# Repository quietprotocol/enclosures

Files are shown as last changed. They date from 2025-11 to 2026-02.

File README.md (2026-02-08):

# OpenMANET Enclosures

This repository collects 3D-printable and off-the-shelf enclosure designs that support OpenMANET nodes and accessories.

## Available Enclosures

| Name | Description |
|---|---|
| [Get Started Enclosure](GetStarted/README.md) | Simple Snap-fit Raspberry Pi 4 + HaLow enclosure with multiple UPS/no-UPS variants and ABS/ASA print guidance. |
| [OpenNot5](OpenNot5/README.md) | Aluminum or 3D printed field chassis that integrates a Pi 4B, Waveshare 3S UPS, and waterproof bulkhead connectors. MakerWorld listing: https://makerworld.com/en/models/2128181-openmanet-radio-case |
| [OpenChubNET](OpenChubNET/README.md) | 3D printed, Pi4B, Waveshare UPS D, CAZN connectors. Option for DIY top lids |
| [Hammond Enclosure](Hammond/README.md) | OpenMANET enclosure for a Pi 4B using a Hammond 1457K1201BK case plus printed cap/carrier tray; optional inline connector simplifies switch-to-PiSugar wiring for easier rework. |

## Other Prints

| Name | Description |
|---|---|
| [GIZOisNT](GIZOisNT_Antenna/README.md) | Tactical Gooseneck Antenna |

## Photo Gallery

**Get Started**

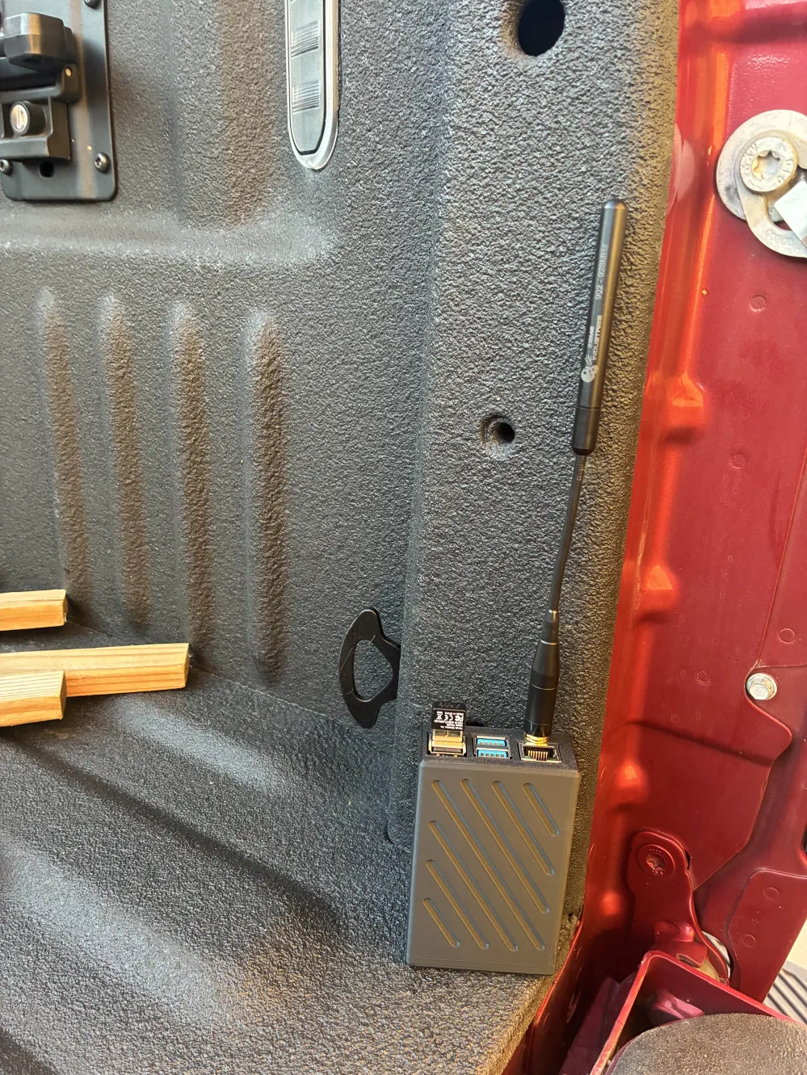
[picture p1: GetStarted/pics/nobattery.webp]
Get Started no-UPS build


**OpenNot5**

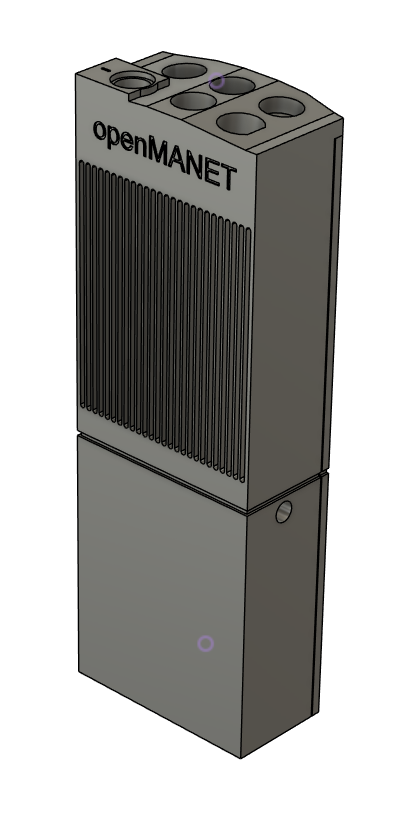
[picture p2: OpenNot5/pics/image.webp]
OpenNot5 field build


**OpenChubNET**

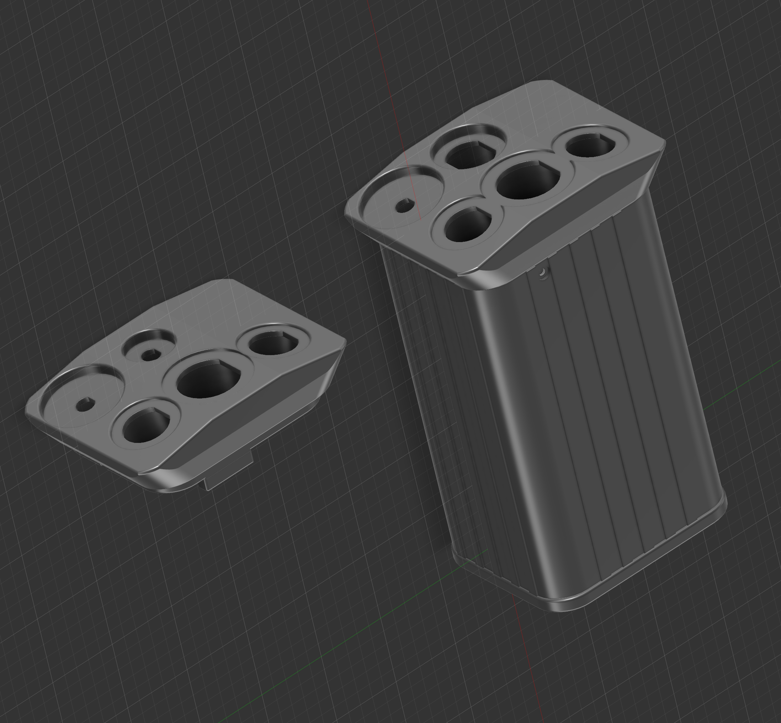
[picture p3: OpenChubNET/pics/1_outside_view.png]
OpenChubNET render


**Hammond**

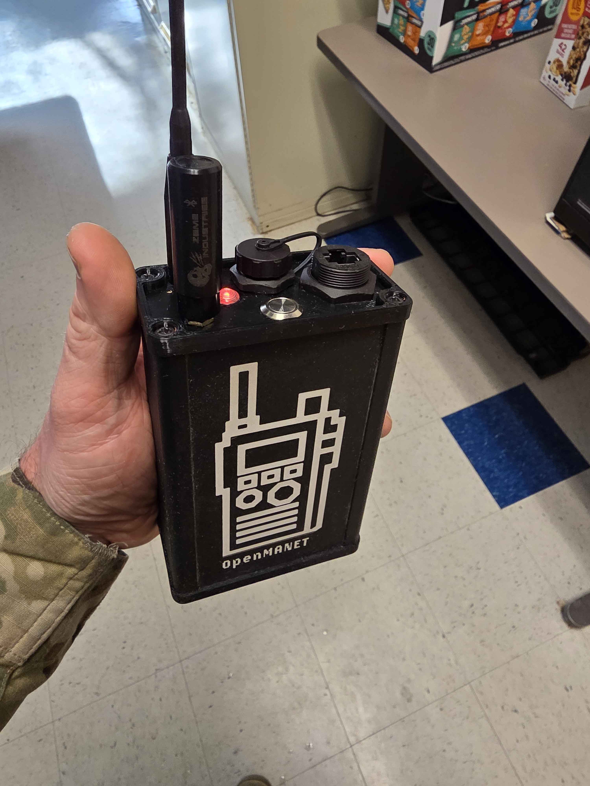
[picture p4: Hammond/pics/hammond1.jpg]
Hammond enclosure front angle


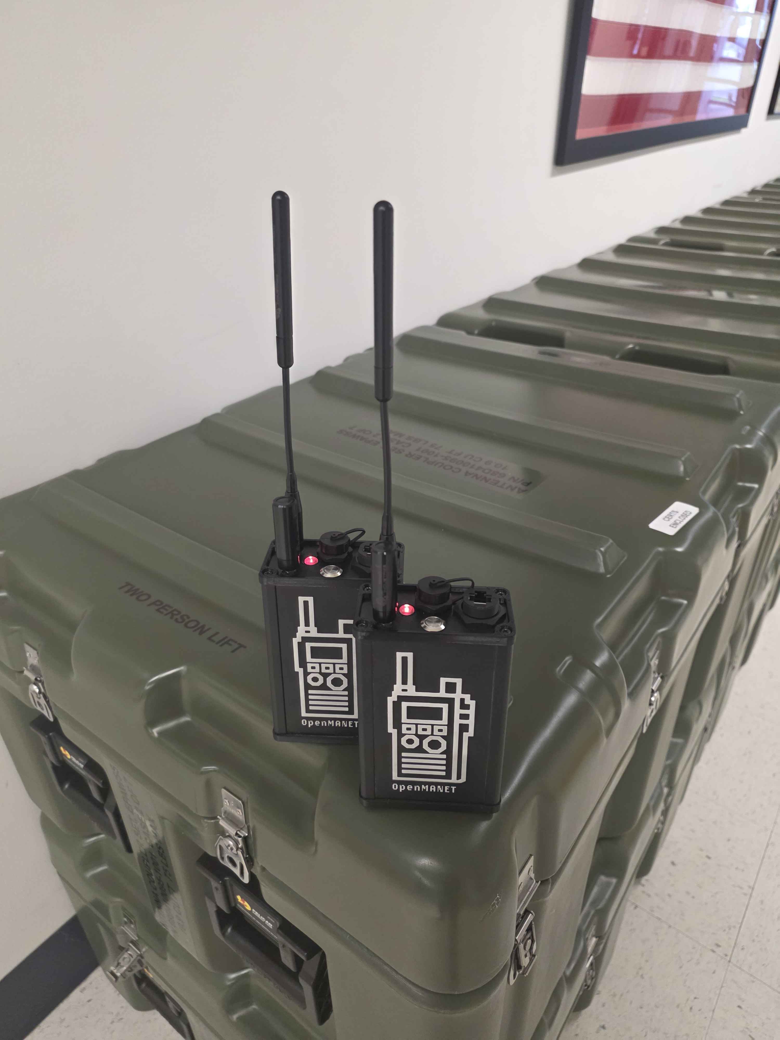
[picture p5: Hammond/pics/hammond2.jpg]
Hammond enclosure rear angle


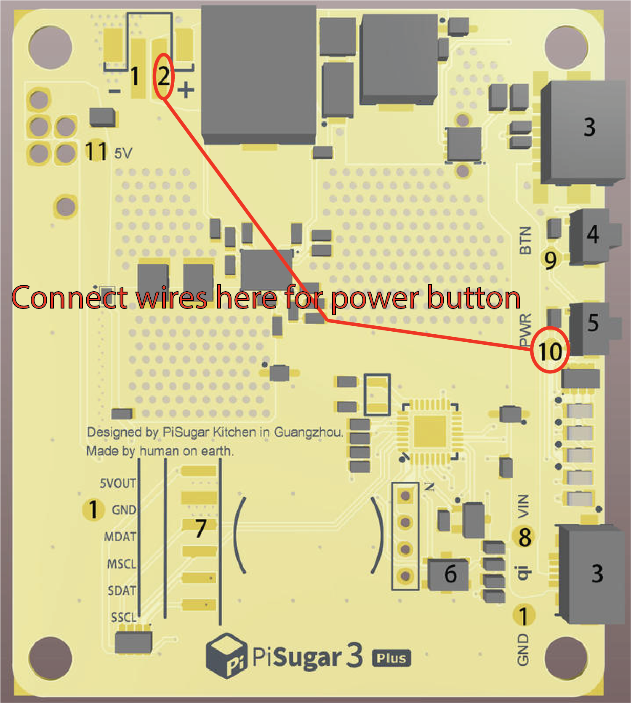
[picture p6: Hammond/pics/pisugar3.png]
Hammond enclosure open with PiSugar 3 Plus


**GIZOisNT**

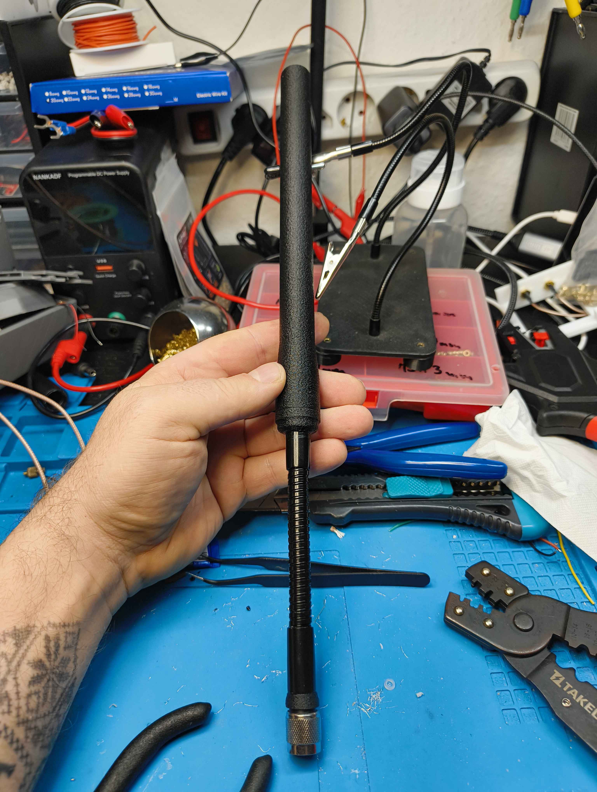
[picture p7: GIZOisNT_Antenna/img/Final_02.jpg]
GIZOisNT


## Contributing

1. Create a directory named after your enclosure.
2. Add a `README.md` describing the use case, assembly steps, and parts list (note optional vs required parts).
3. Include any supporting assets (STL files, wiring diagrams, photos) inside the same directory.

PRs that follow the structure above make it easier for others to build repeatable OpenMANET hardware.

## License

All content in this repository is provided under the [Creative Commons Attribution-NonCommercial 4.0 International](LICENSE) license. Commercial use requires explicit permission from the creator.

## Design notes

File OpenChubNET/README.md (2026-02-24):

# OpenChubNET Enclosure

## Overview
This enclosure is designed for OpenMANET field nodes and integrates a Pi 4B with an internal battery-backed UPS.

## Philosophy

- A large enough case to fit the bulkiest SBC + UPS + Hat configuration. Room on one side of the case to pass through thin USB to power and USB eth.
- A mounting board that the SBC sits on which slides into the case, it has holes to pass through cables. The board translates different SBC + UPS + Hat configurations to fit the case
- Multiple top lids with various antenna configurations depending on antenna types, number of antennas, Power over USB, EUD eth over USB, buttons etc.

## Order of build

1. Print files 
2. Mount the Pi4B and Waveshare UPS D to the printed mounting plate. Use the Waveshare UPS D flat head screws
3. Add the Li-ion battery and wiring
5. Assemble connectors to lid
6. Connect antennas
7. Connect USB cables to hardware
8. Install and test OpenMANET as per [instructions](https://openmanet.github.io/docs/initial-setup.html)

Assembly images can be found at https://www.instagram.com/p/DSH5yTLCO6E

## Parts List

### Baseline
- 1 x Raspberry Pi 4B
- 1 x [Waveshare UPS HAT D](https://www.waveshare.com/ups-hat-d.htm)
- 2 x 21700 3.7V rechargeable lion batteries

### Connectors
- 2 x [CAZN USB-C waterproof port](https://www.aliexpress.us/item/3256806032665821.html)
- 1 x [CAZN RJ45 waterproof](https://www.aliexpress.com/item/1005006207254042.html)
- (alternative) 1 x [CAZN RJ45 waterproof 180 degrees](https://www.aliexpress.com/item/1005006207174223.html)

### Antenna cables
- 1 x [NType to UFL RG178 20cm](https://www.aliexpress.com/item/1005008877279360.html)
- 1 x [SMA to UFL 20cm](https://www.aliexpress.com/item/1005005697399884.html)

### Antennas
- 1 x [Gizont 915MHz gooseneck NType](https://www.aliexpress.com/item/1005006433957349.html)
- 1 x [Gizont GPS Stubby](https://www.aliexpress.com/item/1005006022171372.html)

## Options

### Antenna cables

I went with NType and thicker RG178 cables, but TNC or SMA options are available at resellers.

### Antennas

Gooseneck, whips, spring flexible. Check out Gizont store on Aliexpress

### Aliexpress resellers

- [Gizont Factory Store](https://www.aliexpress.com/store/1103206200)
- [CAZN Factory Store](https://www.aliexpress.com/store/1103206200)

## Print instructions

### Case

Print standing up. No supports needed

- [Case](stl/openMANET_enclosure_rpi4_ups_battery_rj45.stl)

### Mounting plate

Print laying down. No supports needed

- [Board](stl/openMANET_mounting_plate.stl)

### Top

Print laying down or at 45 degree for fewer supports. Supports needed.

- [usbc rj45 ntype sma](stl/openMANET_top_usbc_rj45_ntype_sma.stl)
- [usbc rj45 sma sma](stl/openMANET_top_usbc_rj45_sma_sma.stl)

## DIY top lids

There is a [top lid stencil](stl/openMANET_stencil_top.stl) which can be use to punch out holes to your liking

Additionally there are punches for 

- [CAZN RJ45](stl/openMANET_stencil_cazn_rj45.stl)
- [CAZN USB](stl/openMANET_stencil_cazn_usb.stl)
- [NType](stl/openMANET_stencil_ntype.stl)
- [SMA Large](stl/openMANET_stencil_sma_large.stl)
- [SMA Small](stl/openMANET_stencil_sma_small.stl)

In Fusion 360 add the stencils to the top, combine, cut. 

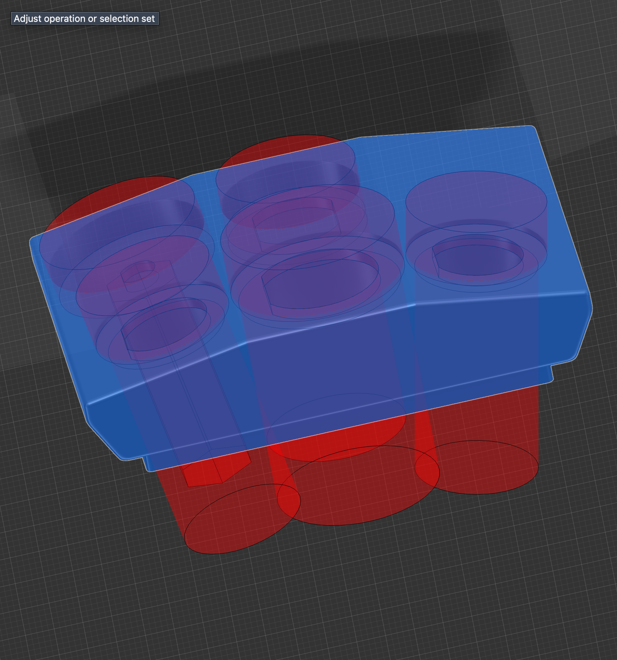
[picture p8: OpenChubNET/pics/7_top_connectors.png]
Result


## Bambu Labs project

- [OpenChubnet slim](stl/OpenChubnet_slim.3mf)

## Reference images

Outside view
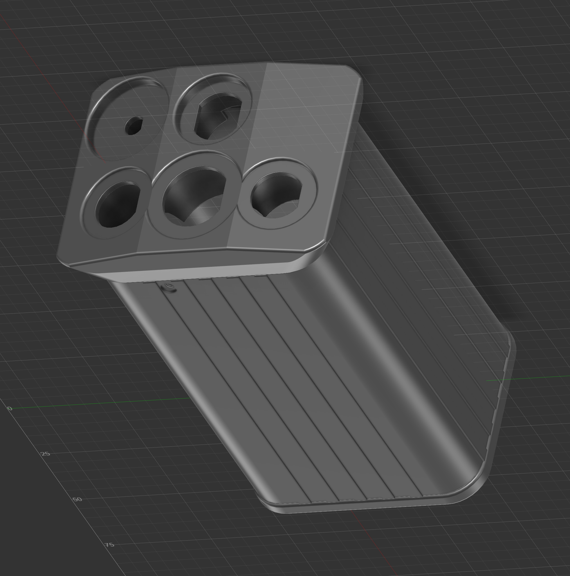
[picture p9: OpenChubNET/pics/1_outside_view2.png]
Outside view

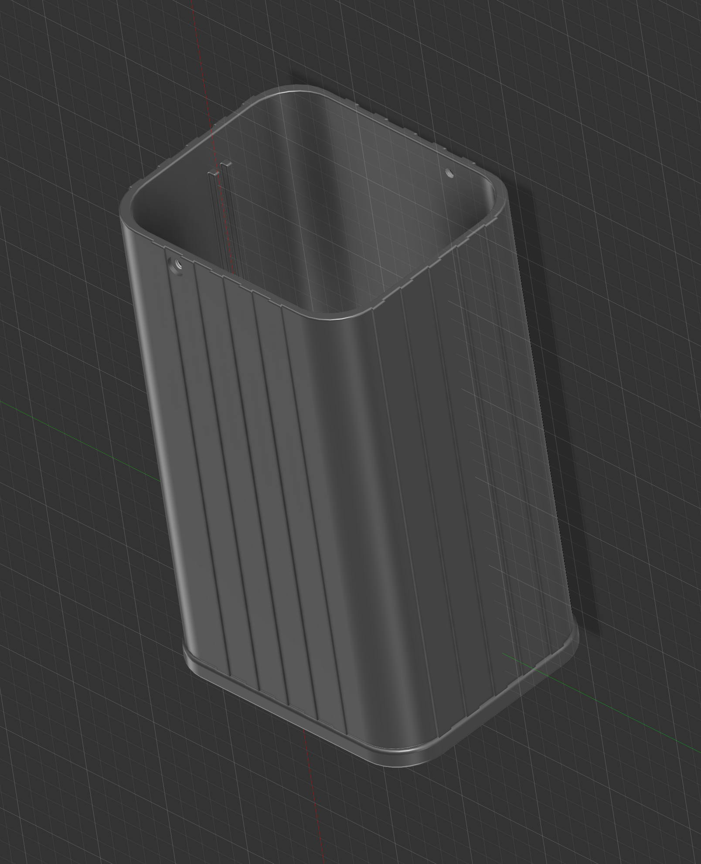
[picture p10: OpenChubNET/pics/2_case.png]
Case

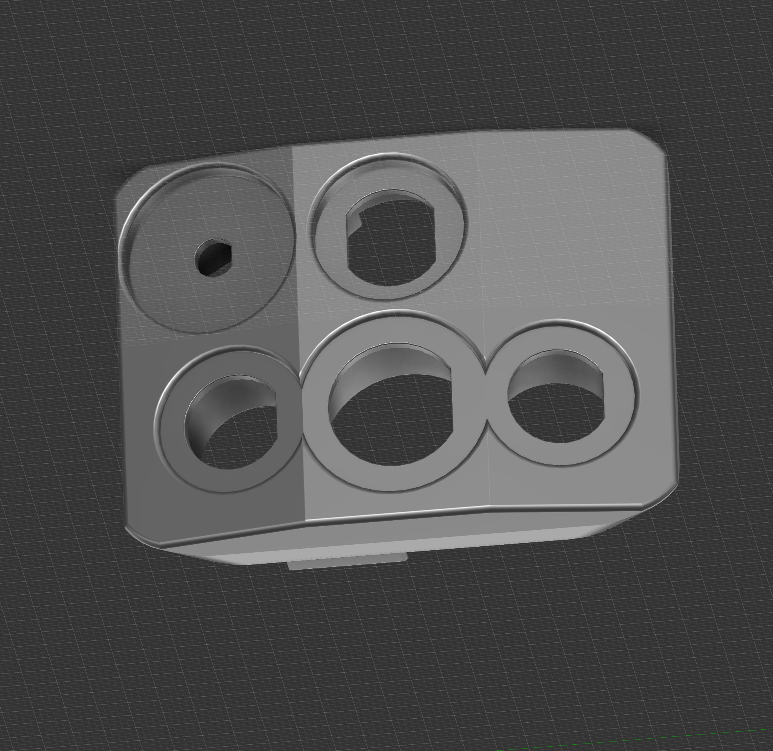
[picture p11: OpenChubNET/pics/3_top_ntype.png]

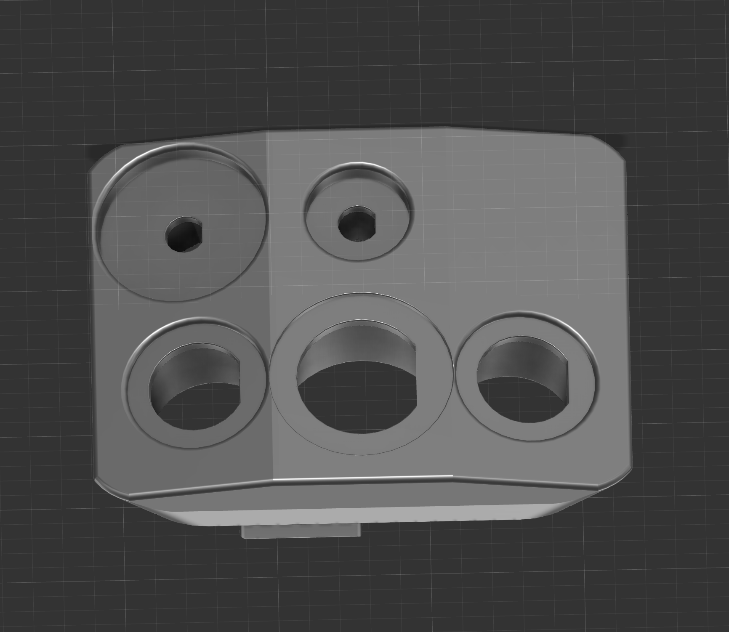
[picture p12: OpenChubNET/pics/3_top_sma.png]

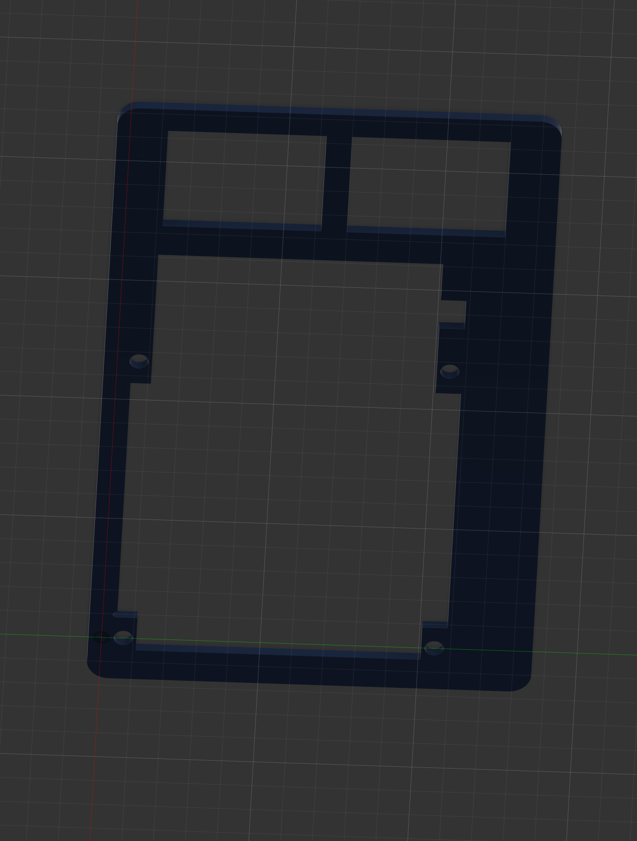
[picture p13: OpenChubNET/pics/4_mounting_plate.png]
Mounting plate

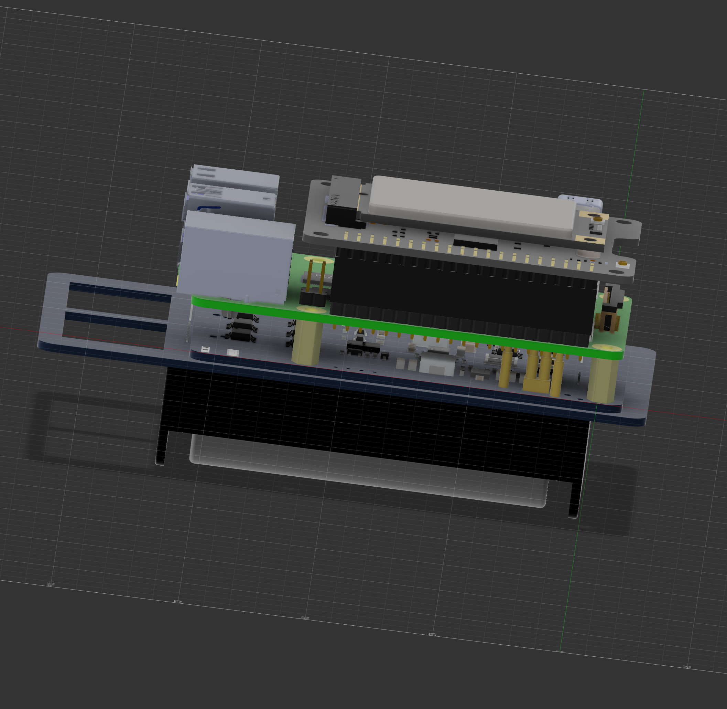
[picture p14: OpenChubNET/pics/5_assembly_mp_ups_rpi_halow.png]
Assembly 1

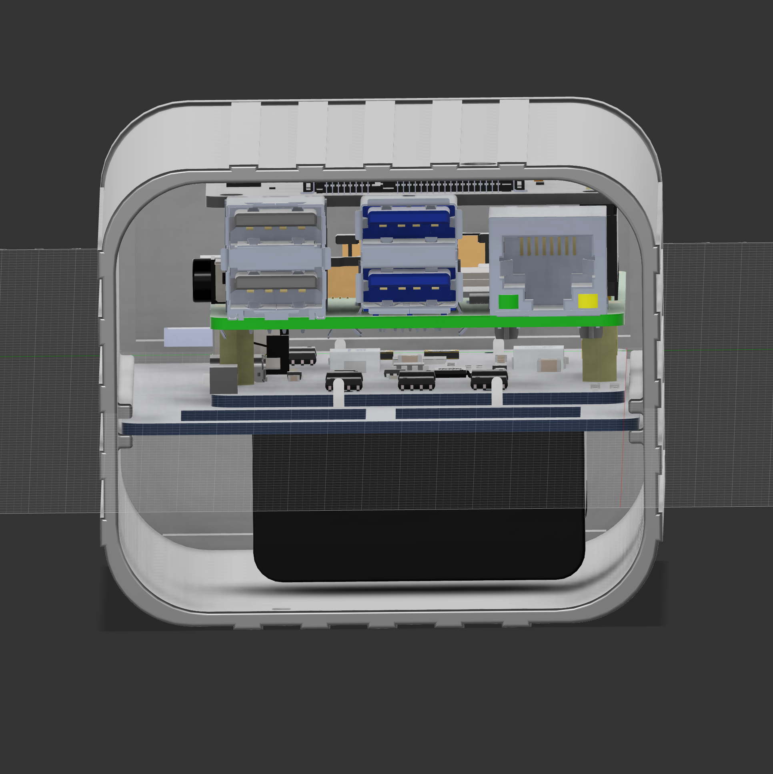
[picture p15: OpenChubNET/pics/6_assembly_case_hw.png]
Assembly 2


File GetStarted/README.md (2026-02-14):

# Get Started Enclosure

This directory captures the baseline enclosure that ships with Get Started kits. It houses a Raspberry Pi 4, HaLow radio, and optional UPS hardware inside a snap-fit shell that prints on a 220 mm bed.

## Overview

- Three variants share the same IO layout but differ in battery accommodation: Pisugar UPS, Waveshare UPS D, or a no-UPS shell.
- Lid uses a flexible latch that survives repeated openings when printed in ABS/ASA.
- External buttons are split into a separate part to keep tolerances tight and maintain layer adhesion.

## Reference Photo

No-UPS reference build

> Add additional perspective photos to `pics/` so other builders can see connector routing and antenna placement.

## Variant Files

| Variant | Main Body / Hatch STL | UPS Support | SMA to U.FL Pigtails |
|---|---|---|---|
| Pisugar UPS | `open manet enclosure pisugar ups main body.stl`, `open manet enclosure pisugar ups hatch.stl`, `open manet enclosure pisugar ups external buttons.stl` | Pisugar 3 power platform | 2 × 6" pigtails |
| Waveshare UPS D | `open manet enclosure WAVESHARE UPS D main body.stl`, `open manet enclosure WAVESHARE UPS D hatch.stl` | Waveshare UPS D + 18650 sled | 1 × 6" pigtail |
| No UPS | `open manet enclosure no ups main body.stl`, `open manet enclosure no ups hatch.stl` | None – direct external power | 1 × 6" pigtail |

All CAD source files (`*.f3z`) for each variant are included for remixing. Keep the SMA jack spacing consistent so the hatch remains reusable between versions.

## Printing Guidance

- Strongly prefer ABS or ASA for every structural part; the enclosure runs warm and the snap joints need ductility.
- Orient the main body with the front face down so the internal standoffs print cleanly and support the Pi with minimal cleanup.
- Print the external button part flat on its back so perimeters align with the travel direction—this maximizes layer adhesion across the narrow bridge between buttons.
- Use 0.2 mm layers, 4 perimeters, and ≥30% infill for the main body; lids can drop to 3 perimeters.

## Recommended Parts

| Item | Optional | Notes |
|---|---|---|
| Wio WM6180 Wi-Fi HaLow mini PCIe Module | No | Primary radio |
| WM1302 Pi Hat | No | Mate the HaLow card to the Pi |
| External Antenna 868/915 MHz 2 dBi SMA Foldable | No | Two ports for UPS builds, single port for no-UPS |
| [ZBM2 Mesh Goose Neck](https://zbm2industries.com/products/mesh-goose-neck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) | Yes | 915 MHz LoRa/HaLow option with higher gain |
| [ZBM2 Mesh Stubby](https://zbm2industries.com/products/mesh-stubby) | Yes | Compact Bluetooth/short-range diagnostic antenna |
| SMA to U.FL cable assembly, 6" (150 mm) | No | Qty depends on variant above |
| Raspberry Pi 4 Model B (1 GB or greater) | No | Core compute |
| 21700 Rechargeable Batteries | Yes | Only for UPS builds that support them |
| Waveshare UPS B/D board | Yes | Use with corresponding enclosure files |
| Pisugar UPS 3 | Yes | Use with Pisugar variant |
| Panda PAU06 USB Wi-Fi Adapter | Yes | Optional client radio |
| USB GPS Receiver (u-blox based) | Yes | Optional timing source |

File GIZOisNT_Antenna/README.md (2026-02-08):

"Mom, can we have GIZONT tactical gooseneck antennas?" - "We have GIZONT actical gooseneck antennas at home...!"

[the GIZONT... GIZOisNT we have / make at home] 

GIZOisNT 

# The GIZOisNT Tactical Gooseneck Antenna
### What the heck is this?
The "GIZOisNT" antenna isn't an antenna in the traditional sense. It's more of a protective housing for various types of antennas. The GIZOisNT is a platform for mounting different antennas (WiFi, LoRa, HaLow, etc.) in the style of tactical antennas, such as those found on the Persistent Systems MPU5 or Silvus StreamCaster. GIZONT, on AliExpress, is probably the best-known manufacturer of mockup antennas.

### Why should I build my own antennas?
The original antennas for tactical digital radios can cost up to 300 EUR/USD, if they're even available. Even then, there's no guarantee they'll be suitable for your project. Of course, you could look for suitable mockups on AliExpress, which are available for 25-35 EUR/USD, but with considerable waiting times.

Or: you could order the individual parts from Amazon (1-2 day delivery), take some time for 3D printing those files, and build the perfect antenna for your project at home for under 15 EUR/USD each (incl. the actual antenna).

### What do I need?
The list of required parts and tools is quite manageable. You'll need a soldering iron (fine tip) and solder. Wire strippers, side cutters, and crimping pliers. And of course, you'll need a 3D printer. The individual components required are: a [gooseneck](https://www.amazon.de/dp/B0C2NDY4RJ) (12cm long, 10mm diameter internal and external threads), a [male TNC connector](https://www.amazon.de/dp/B0D9LDKLXH?th=1), a [male RP-SMA connector](https://www.amazon.de/dp/B08F4SX8YJ?th=1), and [RG316 coaxial cable](https://www.amazon.de/dp/B09PT81P3N?th=1). Last but not least, you'll need the appropriate antenna. Since I built this antenna for a different project, I'm using a [2.4/5GHz antenna](https://www.amazon.de/dp/B06XB92KNF). Regardless of which antenna you ultimately install in the GIZOisNT, the connector must be RP-SMA, and the antenna diameter must not exceed 13mm. Three tubes are available in different lengths: 100mm, 150mm, and 200mm.

### Where do I start?
It's very simple: first, you download the necessary print files. You can find a list of the individual parts [here](<model files/content.md>). You can either experiment with your own printer settings or use [my presets](<printer files/printer_settings.md>). If you're using an Anycubic Kobra S1, you can directly process the included 3MF file. However, if you're using the Orca, Prusa, or Bambu slicer, you can load the 3MF file, but you may need to make some adjustments.

I suggest you print the individual parts in two batches: first the small parts, and then the tube. The tube takes a very long time to print, so you can start working on the small parts in the meantime. Even if you plan to build multiple GIZOisNTs, print the small parts first, then the tubes.

### What's next?
Once your parts are printed, follow my [assembly guide](img/assembly/assembly.md).

---

The GIZOisNT antenna was developed by [audiocustoms](https://github.com/audiocustoms) for [ORBIS Mesh](https://github.com/ORBIS-Mesh) and [openMANET](https://openmanet.github.io/docs/).

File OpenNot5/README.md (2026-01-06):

# Open Not 5 Node Enclosure

## Overview
This enclosure is designed for OpenMANET field nodes and integrates a Pi 4B with an internal battery-backed UPS.  
The aluminum chassis doubles as a passive heatsink and keeps all IO accessible through waterproof bulkhead ports. This also can be 3D printed but may get hot.

Example enclosure build

Printable files and build notes are on MakerWorld: https://makerworld.com/en/models/2128181-openmanet-radio-case

## Assembly
1. Print files 
2. Mount the PI4B and UPS
3. Add the Li-ion battery and wiring
4. add antennas
5. Seal using waterproof screws and gasket.

## Parts List
 - Raspberry Pi 4B (4 GB preferred)
 - [Waveshare 3S UPS Module](https://www.amazon.com/waveshare-Uninterruptible-UPS-Module-3S/dp/B0BQC2WNR8/) with 12 V barrel output and on/off button
 - 4 × SMA-to-PEX bulkhead connectors with O-rings
 - [CAZN USB-C waterproof port](https://www.aliexpress.us/item/3256806032665821.html)
 - 1 × [ZBM2 Mesh Stubby antenna](https://zbm2industries.com/products/mesh-stubby) for Bluetooth diagnostics
 - 1 × 915 MHz LoRa antenna (SMA) – [ZBM2 Mesh Goose Neck](https://zbm2industries.com/products/mesh-goose-neck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)
 - 2 × dual-band (2.4/5 GHz) Wi-Fi antennas (SMA)
 - 1 × GPS puck antenna (SMA or MMCX depending on receiver)

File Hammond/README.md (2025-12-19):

# Hammond Enclosure

OpenMANET enclosure for a Raspberry Pi 4B that uses a Hammond 1457K1201BK case with a printed cap and carrier tray. An inline connector between the power switch and the PiSugar can be added to make disassembly and reassembly easier.

## Photos

Hammond enclosure front angle

Hammond enclosure rear angle

Hammond enclosure open with PiSugar 3 Plus

## Bill of Materials

| # | Part | Qty | Part Number | Link | Vendor/Notes |
|---|---|-----|---|---|---|
| 1 | Enclosure | 1 | 1457K1201BK | https://www.hawkusa.com/manufacturers/hammond-mfg/enclosures/1457k1201bk | Hammond |
| 2 | Pi 4B | 1 | Any model | https://www.digikey.com/en/product-highlight/r/raspberry-pi/raspberry-pi-4-model-b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 | — |
| 3 | Light pipe | 1 | LCS_072_CTP | https://www.digikey.com/en/products/detail/visual-communications-company-vcc/LCS-072-CTP/5156883 | VCC |
| 4 | Wi-Fi HaLow card | 1 | Wio-WM6108 | https://www.seeedstudio.com/Wio-WM6180-Wi-Fi-HaLow-mini-PCIe-Module-p-6394.html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 | Seeed |
| 5 | Wi-Fi hat | 1 | WM1302 | https://www.seeedstudio.com/WM1302-Pi-Hat-p-4897.html | Seeed |
| 6 | USB-C connector | 1 | E10 FPC-BF-F/PFC-A-M- | https://www.aliexpress.us/item/3256806033375623.html | Cazn, 0.2 m |
| 7 | RJ45 connector | 1 | RJ45-TF1-F/RJ45-M- | https://www.aliexpress.us/item/3256806020939290.html | Cazn, 0.3 m |
| 8 | u.fl to RP-SMA pigtail | 2 | Any | https://www.aliexpress.us/item/3256809083730864.html | 8 cm |
| 9 | Button | 1 | GQ12H2 | https://www.amazon.com/dp/B08R9P9DFC/ | Gebildet |
| 10 | PiSugar 3 Plus | 1 | — | https://www.pisugar.com/products/pisugar-3-plus-raspberry-pi-ups | PiSugar |

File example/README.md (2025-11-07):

# Example Enclosure

This sample enclosure documents the expected level of detail for OpenMANET builds. Use it as a starting point when you document your own hardware, swapping in your enclosure-specific files, wiring notes, and mechanical considerations.

## Overview

- Houses a Raspberry Pi 4, HaLow radio, antennas, and optional power accessories.
- Demonstrates how to call out required vs optional parts so builders can adapt to their needs.
- Intended for field-friendly deployments where ruggedness and quick maintenance matter.

## Reference photo

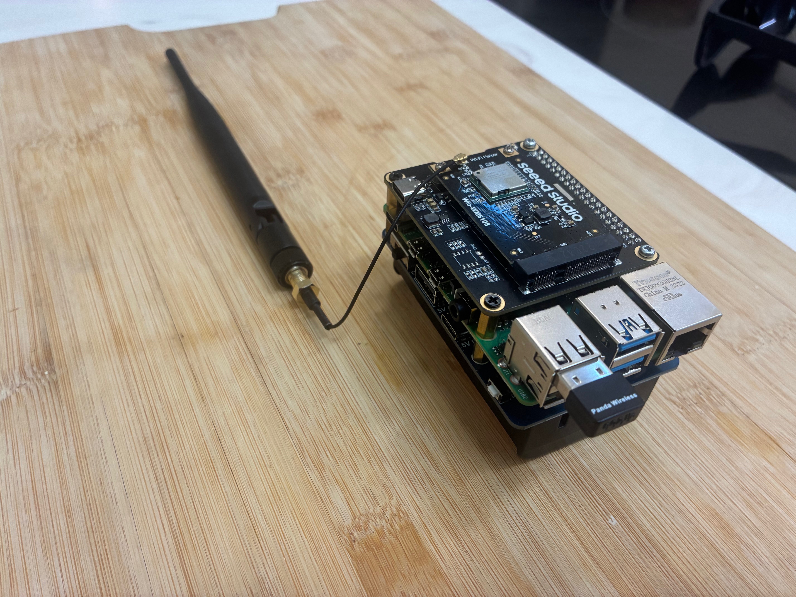
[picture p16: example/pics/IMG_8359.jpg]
Example enclosure build


> Store high-resolution photos inside a `pics/` subdirectory (or similar) and link to them with relative paths so GitHub renders the image inline.

## Recommended Parts List

| Item | Optional |
|---|---|
| [Wio WM6180 Wi-Fi HaLow mini PCIe Module](https://www.seeedstudio.com/Wio-WM6180-Wi-Fi-HaLow-mini-PCIe-Module-p-6394.html) | No |
| [WM1302 Pi Hat](https://www.seeedstudio.com/WM1302-Pi-Hat-p-4897.html) | No |
| [External Antenna 868/915 MHz 2 dBi SMA Foldable](https://www.seeedstudio.com/External-Antenna-868-915MHZ-2dBi-SMA-L195mm-Foldable-p-5863.html) | No |
| [UF.L to SMA-K 1.13 mm Cable (120 mm)](https://www.seeedstudio.com/UF-L-SMA-K-1-13-120mm-p-5046.html) | No |
| [Raspberry Pi 4 Model B (1 GB or greater)](https://www.seeedstudio.com/Raspberry-Pi-4-Computer-Model-B-1GB-p-4078.html) | No |
| [21700 Rechargeable Batteries](https://www.amazon.com/dp/B0D3GX96H6?ref_=ppx_hzsearch_conn_dt_b_fed_asin_title_4) | Yes |
| [WaveShare UPS B (18650 version)](https://www.amazon.com/gp/product/B0D39VDMDP/ref=ox_sc_saved_title_1?smid=A3B0XDFTVR980O&psc=1) | Yes |
| [Panda PAU06 USB Wi-Fi Adapter](https://www.amazon.com/dp/B00762YNMG?ref_=ppx_hzsearch_conn_dt_b_fed_asin_title_1) | Yes |
| [USB GPS Receiver (u-blox based)](https://www.amazon.com/dp/B01MTU9KTF?ref_=ppx_hzsearch_conn_dt_b_fed_asin_title_1) | Yes |

## Assembly notes

1. Mount the Raspberry Pi and WM1302 Pi Hat inside your enclosure, ensuring sufficient clearance for the UF.L cables.
2. Route the UF.L to SMA pigtails through the panel and affix the external antennas to maintain RF performance.
3. If battery-backed, secure the UPS and cells with non-conductive spacers and verify airflow for passive cooling.
4. Document any STL/STEP files, panel cutouts, or wiring diagrams in this directory so others can reproduce the build.

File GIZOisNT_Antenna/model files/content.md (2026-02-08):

## Content List
### Printable files:
- adapter_sma.stl
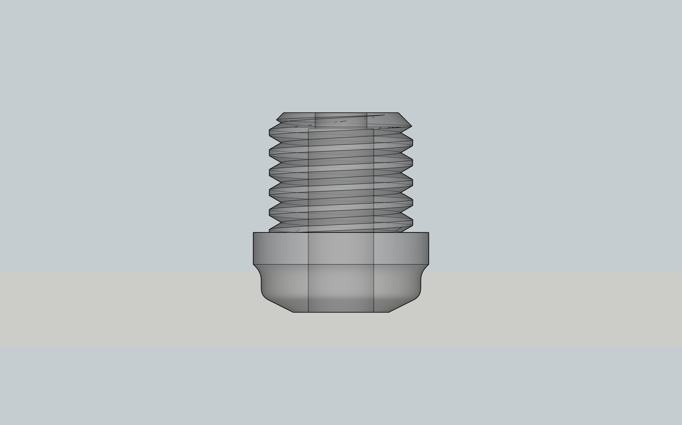
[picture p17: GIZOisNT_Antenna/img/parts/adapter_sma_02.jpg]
adapter_sma.stl

- adapter_tnc.stl
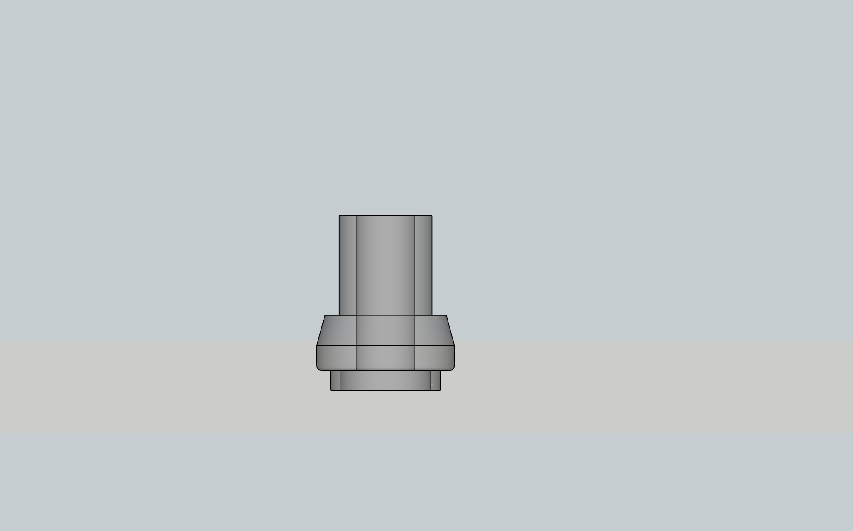
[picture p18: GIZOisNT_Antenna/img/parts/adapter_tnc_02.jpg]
adapter_tnc.stl

- cap.stl
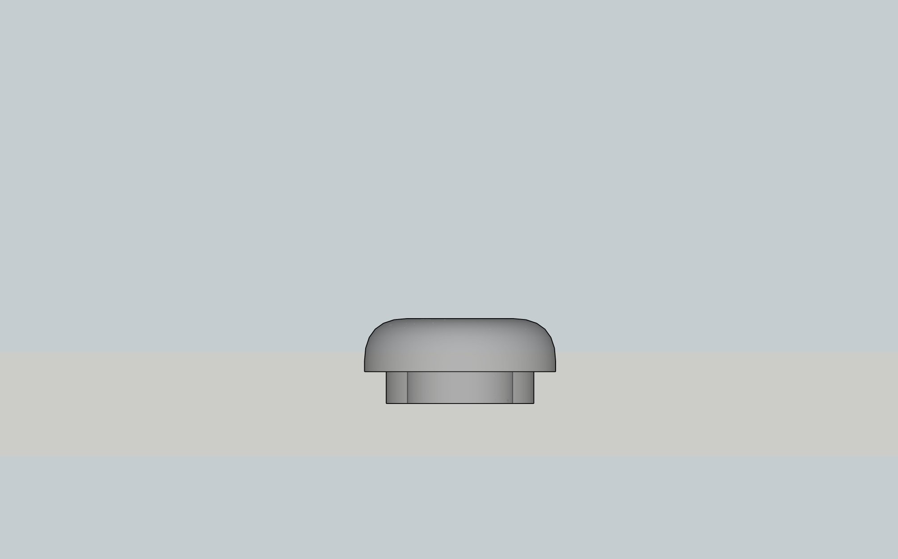
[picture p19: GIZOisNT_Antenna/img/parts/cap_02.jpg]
cap.stl

- tupe_200mm.stl (also 100mm and 150mm length)
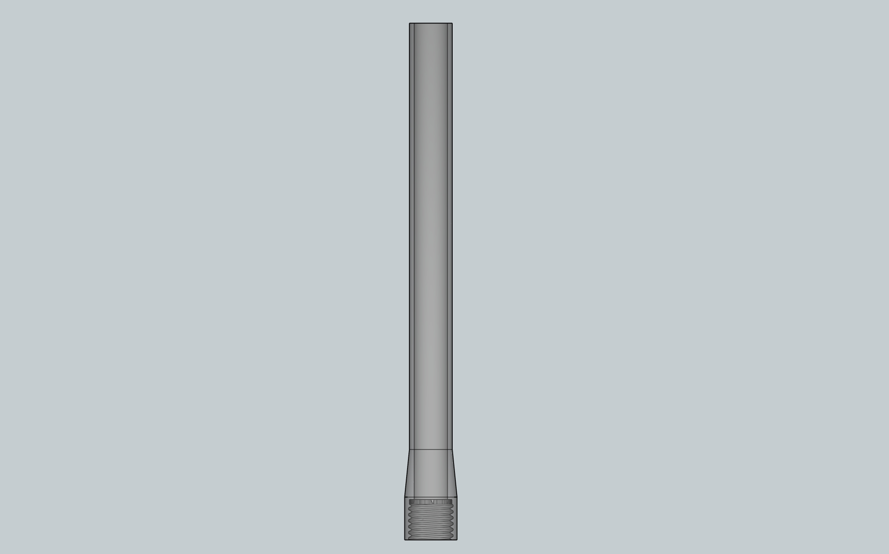
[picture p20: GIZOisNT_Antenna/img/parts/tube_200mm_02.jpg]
tube_200mm.stl


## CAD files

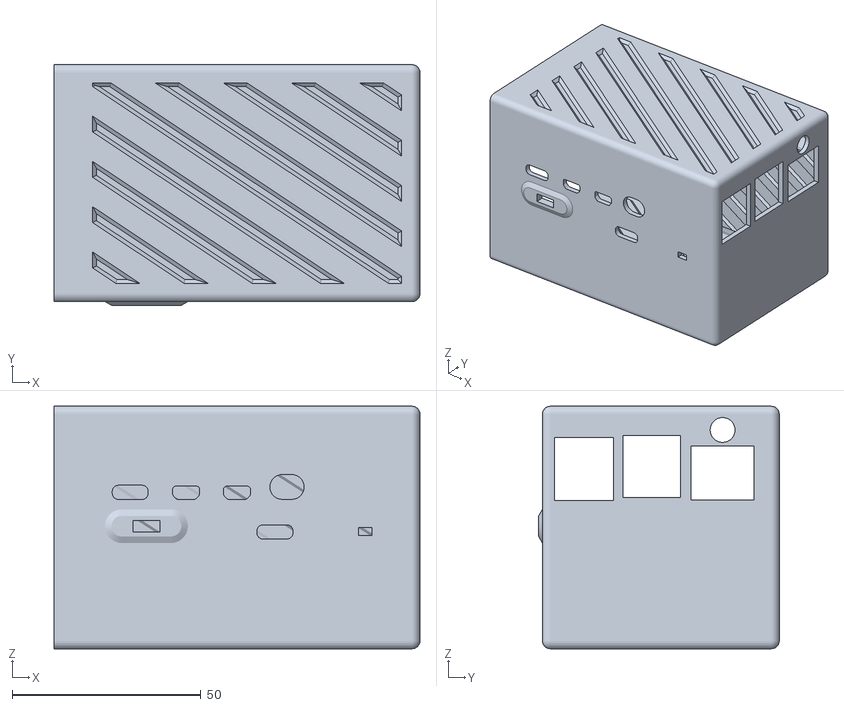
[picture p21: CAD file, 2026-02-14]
GetStarted/stl/open manet enclosure WAVESHARE UPS D main body.stl
97.0 x 63.8 x 64.3

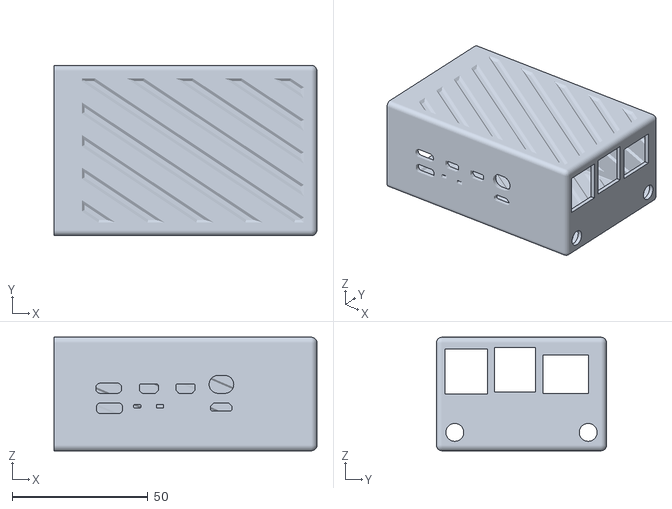
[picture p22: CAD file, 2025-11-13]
GetStarted/stl/open manet enclosure pisugar ups main body.stl
97.0 x 62.8 x 41.9

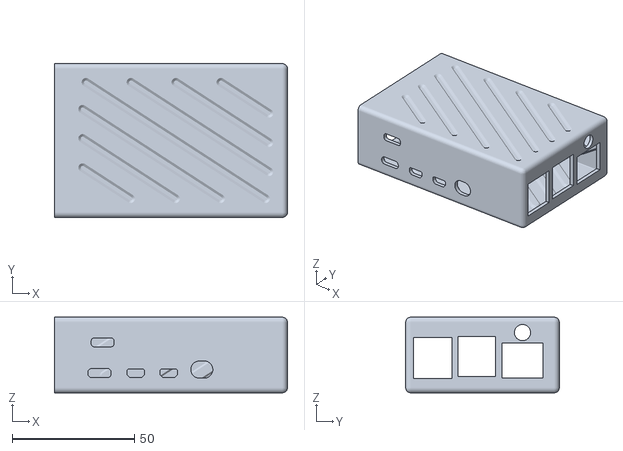
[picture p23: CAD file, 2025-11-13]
GetStarted/stl/open manet enclosure no ups main body.stl
95.2 x 62.8 x 30.9

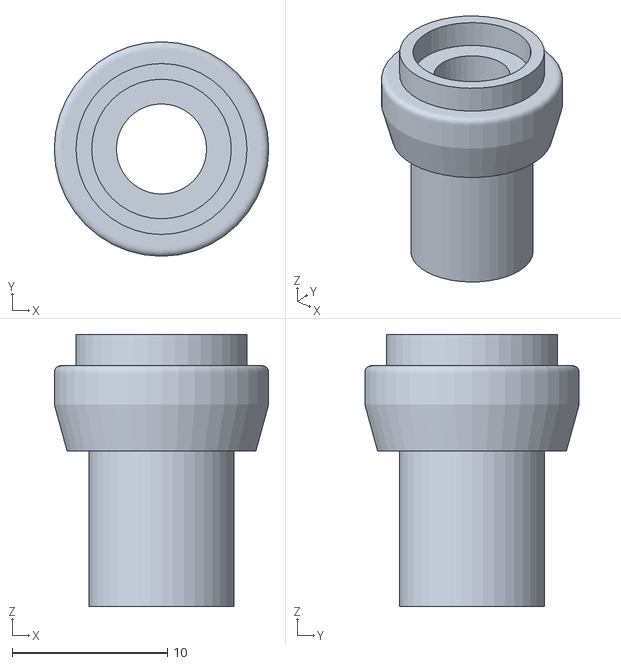
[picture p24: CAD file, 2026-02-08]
GIZOisNT_Antenna/model files/adapter_tnc.stl
13.8 x 13.8 x 17.5

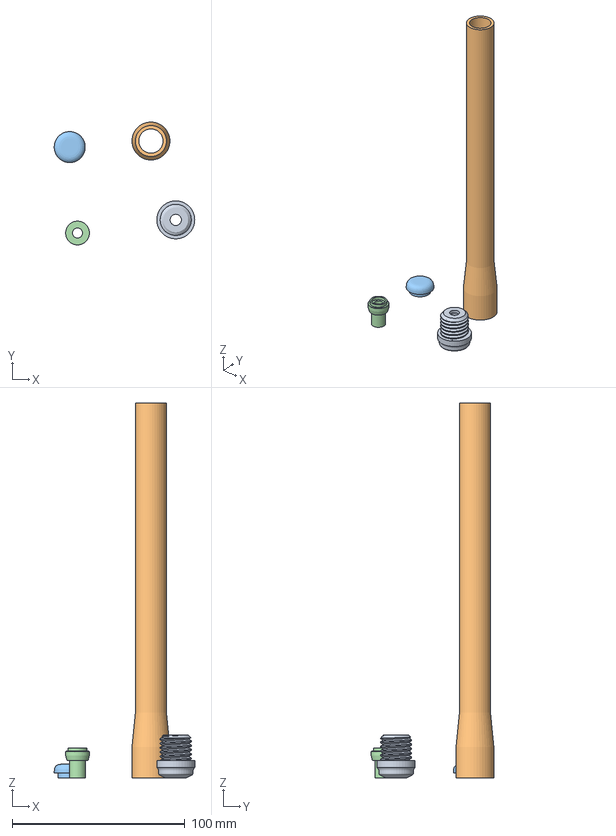
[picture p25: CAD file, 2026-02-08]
GIZOisNT_Antenna/printer files/GIZOisNT.3mf
81.3 x 71.1 x 217.0 mm
adapter_sma.stl
tube_200mm.stl
cap.stl
adapter_tnc.stl

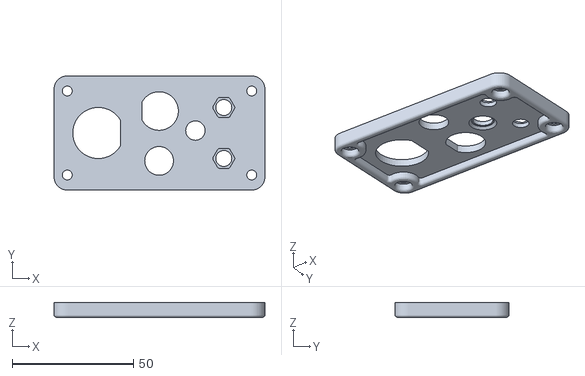
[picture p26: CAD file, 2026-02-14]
Hammond/stl/OpenMANET halow enclosure top cap rev3.stl
87.0 x 47.1 x 6.00

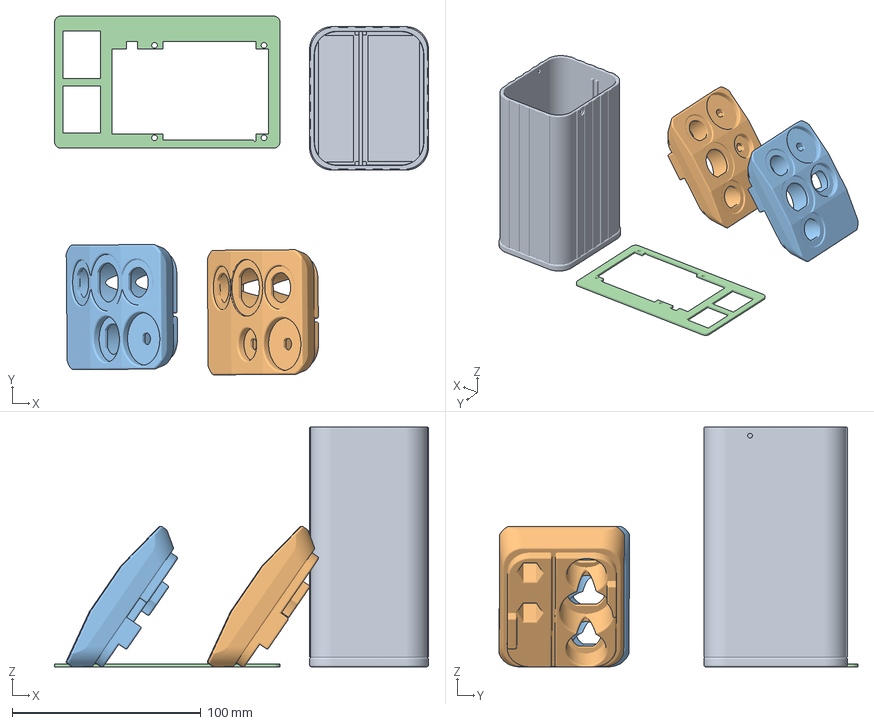
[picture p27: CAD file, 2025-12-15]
OpenChubNET/stl/OpenChubnet_slim.3mf
198.1 x 190.1 x 127.0 mm
Enclosure v4 slimmer v5.stl
openMANET_top_usbc_rj45_sma_sma.stl
openMANET_top_usbc_rj45_ntype_sma.stl
openMANET_mounting_plate.stl

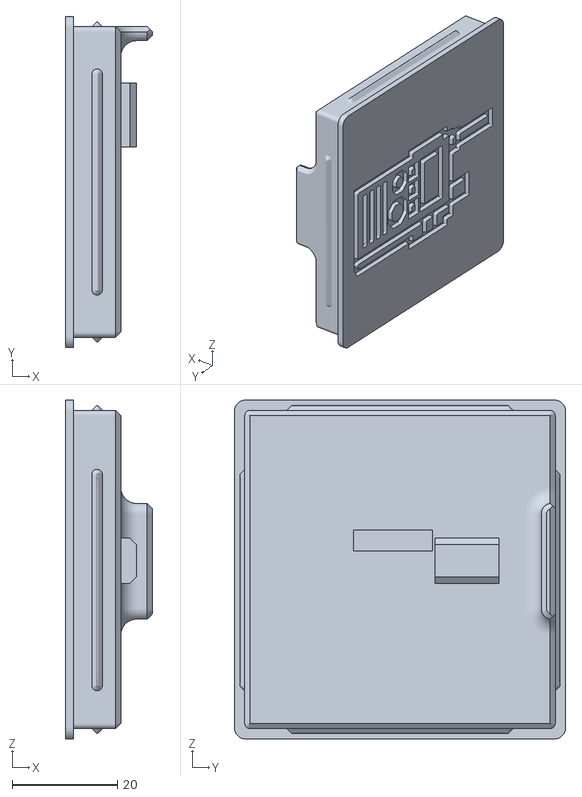
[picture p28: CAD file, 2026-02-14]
GetStarted/stl/open manet enclosure WAVESHARE UPS D hatch REV1.stl.stl
16.5 x 62.8 x 64.3

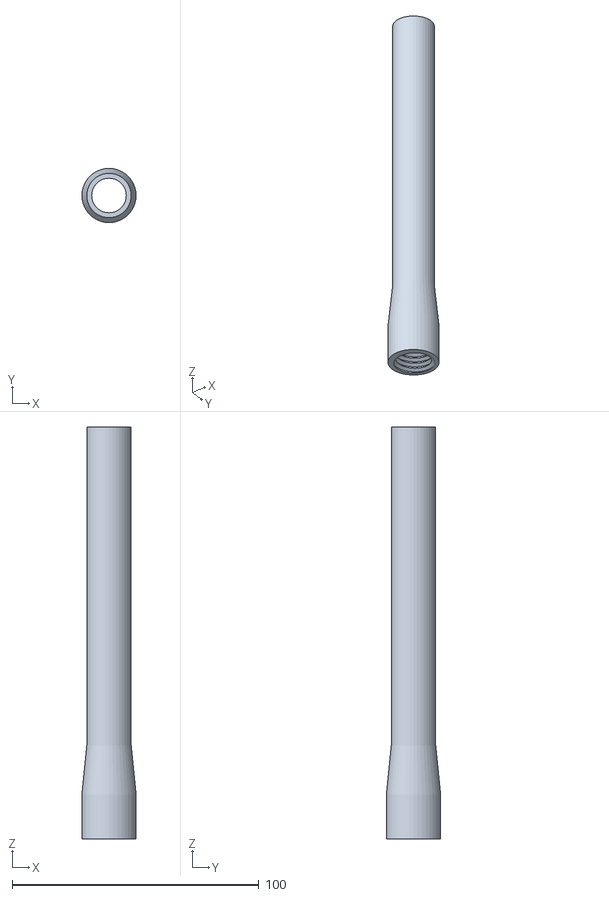
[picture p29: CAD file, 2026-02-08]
GIZOisNT_Antenna/model files/tube_150mm.stl
22.0 x 22.0 x 167.0

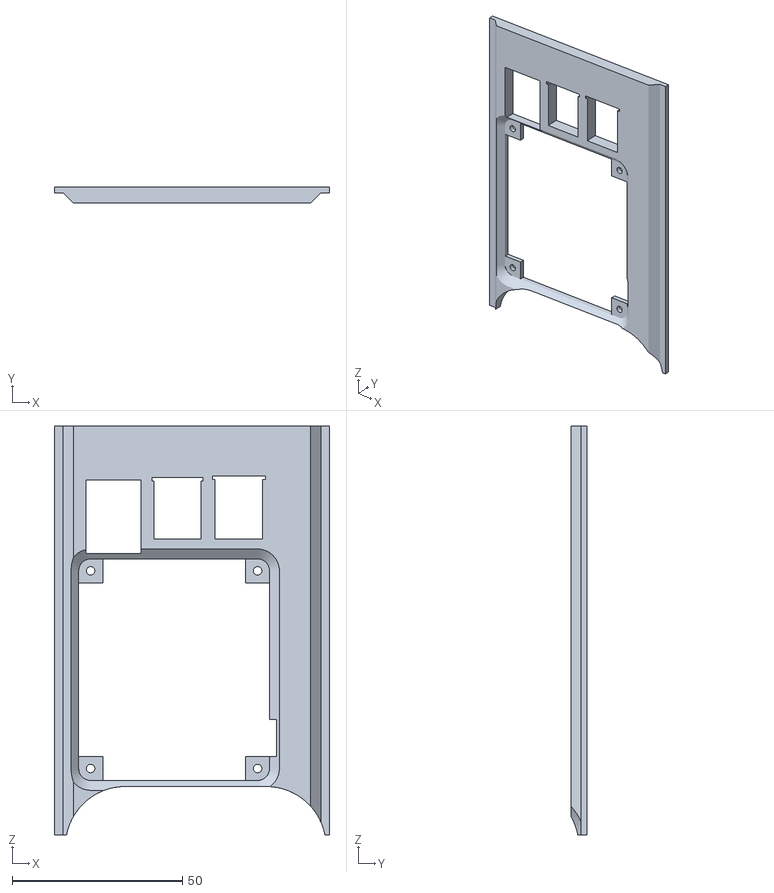
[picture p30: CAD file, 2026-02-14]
Hammond/stl/OpenMANET halow enclosure carrier tray rev3.stl
80.7 x 4.70 x 120.0

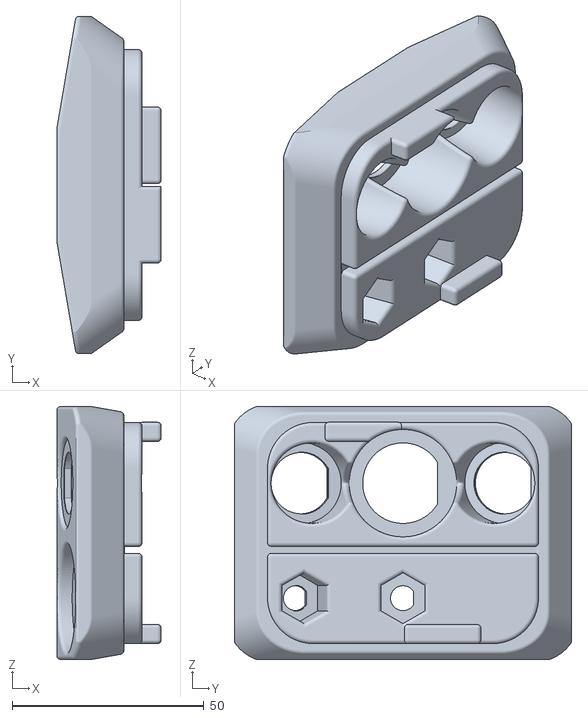
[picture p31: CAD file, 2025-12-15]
OpenChubNET/stl/openMANET_top_usbc_rj45_sma_sma.stl
27.2 x 88.0 x 66.0

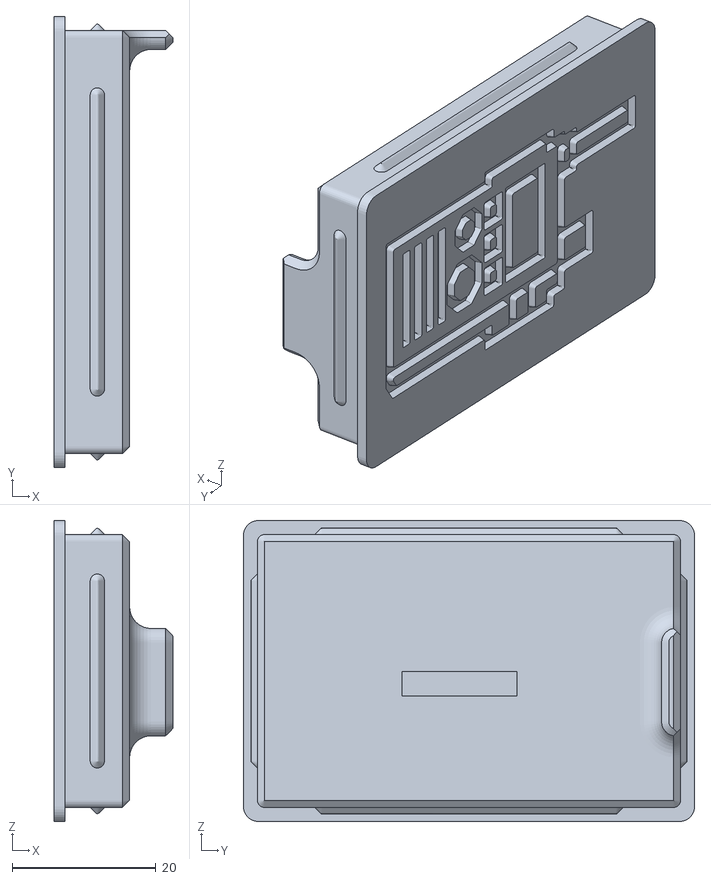
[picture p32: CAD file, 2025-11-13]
GetStarted/stl/open manet enclosure pisugar ups hatch REV1.stl
16.5 x 62.8 x 41.9

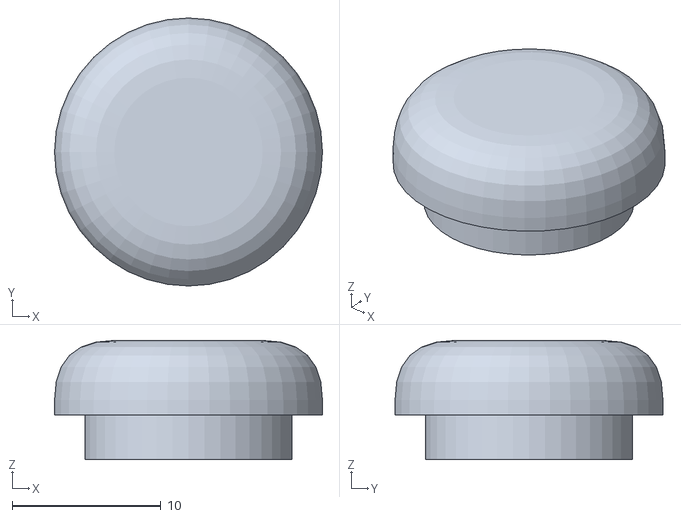
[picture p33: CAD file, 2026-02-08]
GIZOisNT_Antenna/model files/cap.stl
18.0 x 18.0 x 8.00

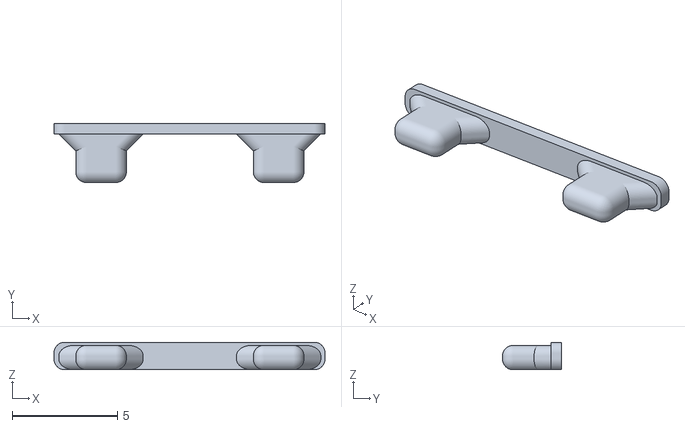
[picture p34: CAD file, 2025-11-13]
GetStarted/stl/open manet enclosure pisugar ups external buttons.stl
12.9 x 2.80 x 1.30

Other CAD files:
OpenChubNET/stl/openMANET_top_usbc_rj45_ntype_sma.stl
GIZOisNT_Antenna/model files/tube_200mm.stl
OpenChubNET/stl/openMANET_enclosure_rpi4_ups_battery_rj45.stl
GIZOisNT_Antenna/model files/adapter_sma.stl
GIZOisNT_Antenna/Sketchup/GIZOisNT_v1.skp
GIZOisNT_Antenna/model files/tube_100mm.stl
GetStarted/stl/open manet enclosure no ups hatch.stl
OpenChubNET/stl/openMANET_mounting_plate.stl
OpenChubNET/stl/openMANET_stencil_cazn_rj45.stl
OpenChubNET/stl/openMANET_stencil_cazn_usb.stl
OpenChubNET/stl/openMANET_stencil_ntype.stl
OpenChubNET/stl/openMANET_stencil_sma_large.stl
OpenChubNET/stl/openMANET_stencil_sma_small.stl
OpenChubNET/stl/openMANET_stencil_top.stl
OpenChubNET/stl/openMANET_stencil_top_base.stl

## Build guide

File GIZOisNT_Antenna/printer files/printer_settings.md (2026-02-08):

## Files

The files ``GIZOisNT_200mm_PETG_0.12_6h47m.gcode`` and ``GIZOisNT.3mf`` where generated with Anycubic Slicer Next. You should be able to load the ``3mf`` file with Orca, Prusa and Bambu Slicer as well.

## Printer Settings

### Filament
JAYO Rapid Matte PETG Filament 1.75mm, High Speed 50-600mm/s. Use the SUNLU PETG Matte presets.

### Temperature
- Nozzle: 230°C
- Bed: 75°C

### Quality
- 0.12mm layer height
- 0.2mm first layer
- 15% filling

### Support
Standard tree (auto).

### Fuzzy Skin (optional)
Only the tube and the modifiers apply Fuzzy Skin
- Fuzzy Skin: Contour
- Noise Type: Classic
- Point Distance: 0.25mm
- Thickness: 0.25mm

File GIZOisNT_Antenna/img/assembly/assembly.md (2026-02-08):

## Assembly Guide

The individual components required are: a [gooseneck](https://www.amazon.de/dp/B0C2NDY4RJ) (12cm long, 10mm diameter internal and external threads), a [male TNC connector](https://www.amazon.de/dp/B0D9LDKLXH?th=1), a [male RP-SMA connector](https://www.amazon.de/dp/B08F4SX8YJ?th=1), and 14,5cm of [RG316 coaxial cable](https://www.amazon.de/dp/B09PT81P3N?th=1).

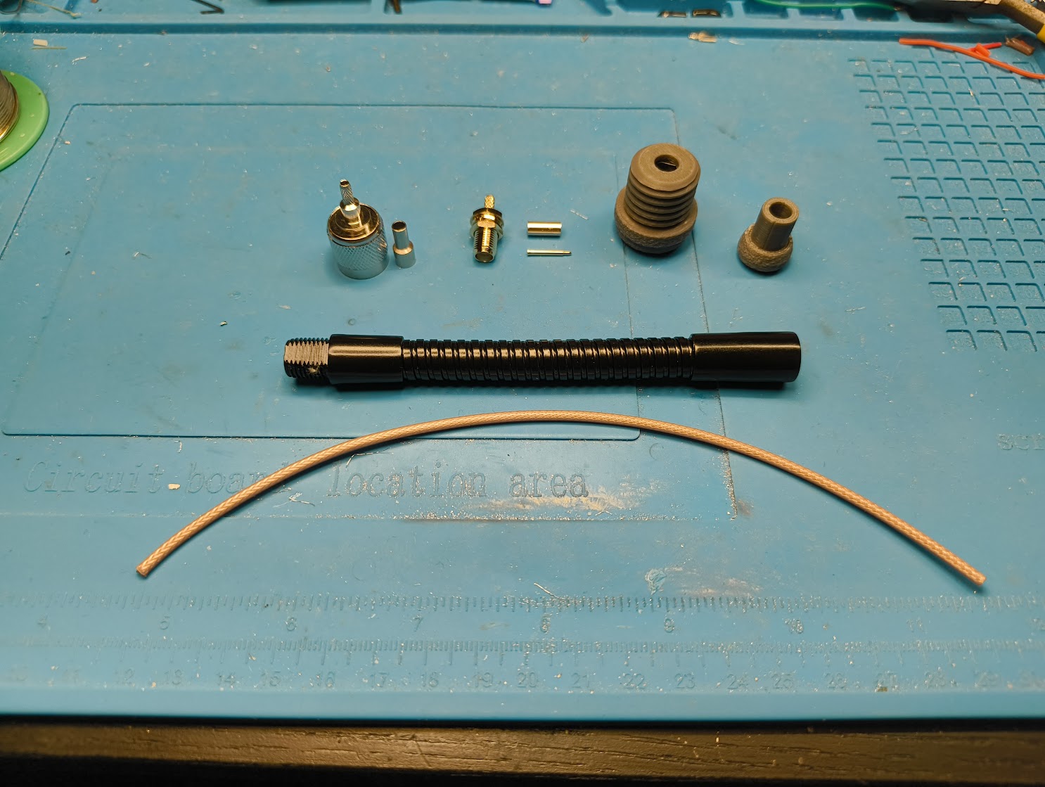
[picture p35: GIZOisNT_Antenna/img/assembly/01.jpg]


### 1. Glue in the TNC adapter
The TNC adapter is almost a press fit into the internal thread of the gooseneck. Once it's in, it's in! Use superglue or Sikaflex to ensure a watertight seal.

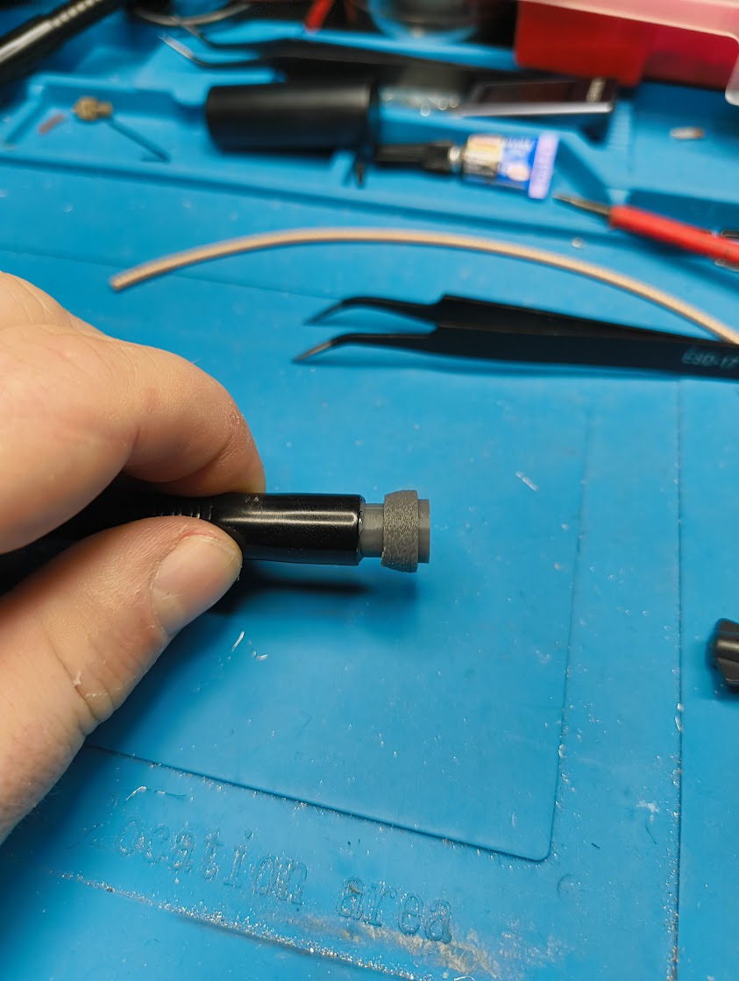
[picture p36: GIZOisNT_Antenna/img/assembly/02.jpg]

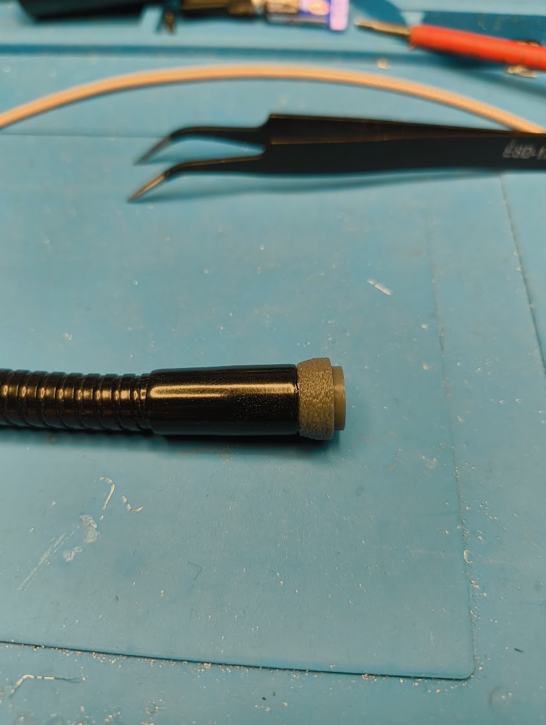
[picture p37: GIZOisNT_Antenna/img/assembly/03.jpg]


### 2. Strip one end of the coaxial cable.
Strip approximately 10-12mm of insulation. Split the shielding and fold it back. Then strip approximately 1-2mm of insulation from the inner conductor and tin it with solder.

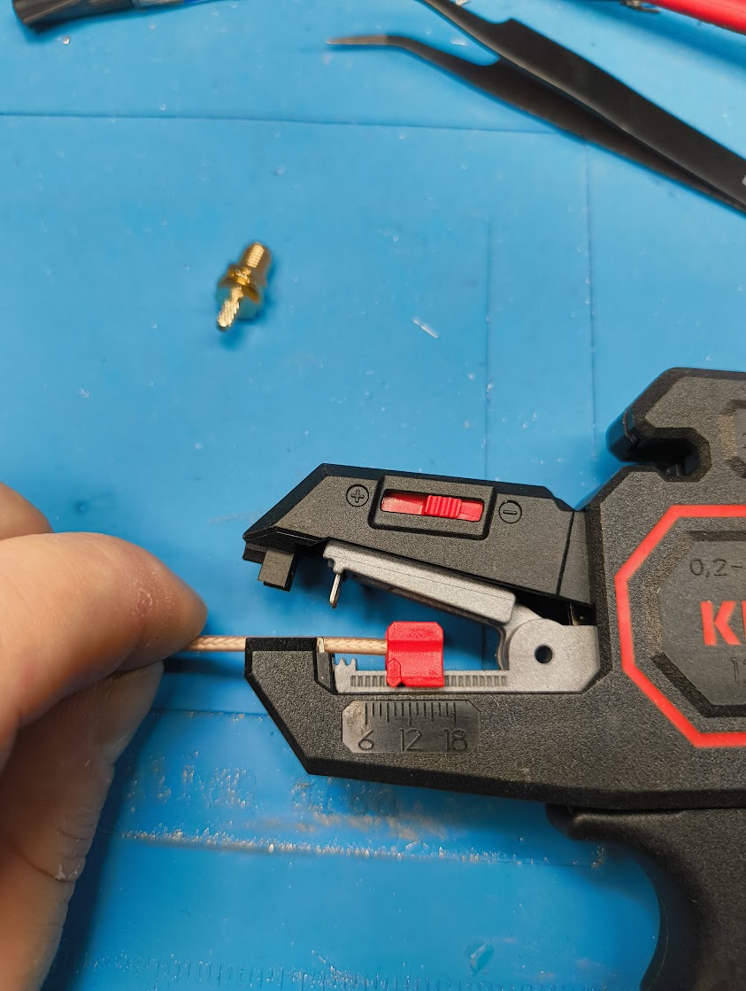
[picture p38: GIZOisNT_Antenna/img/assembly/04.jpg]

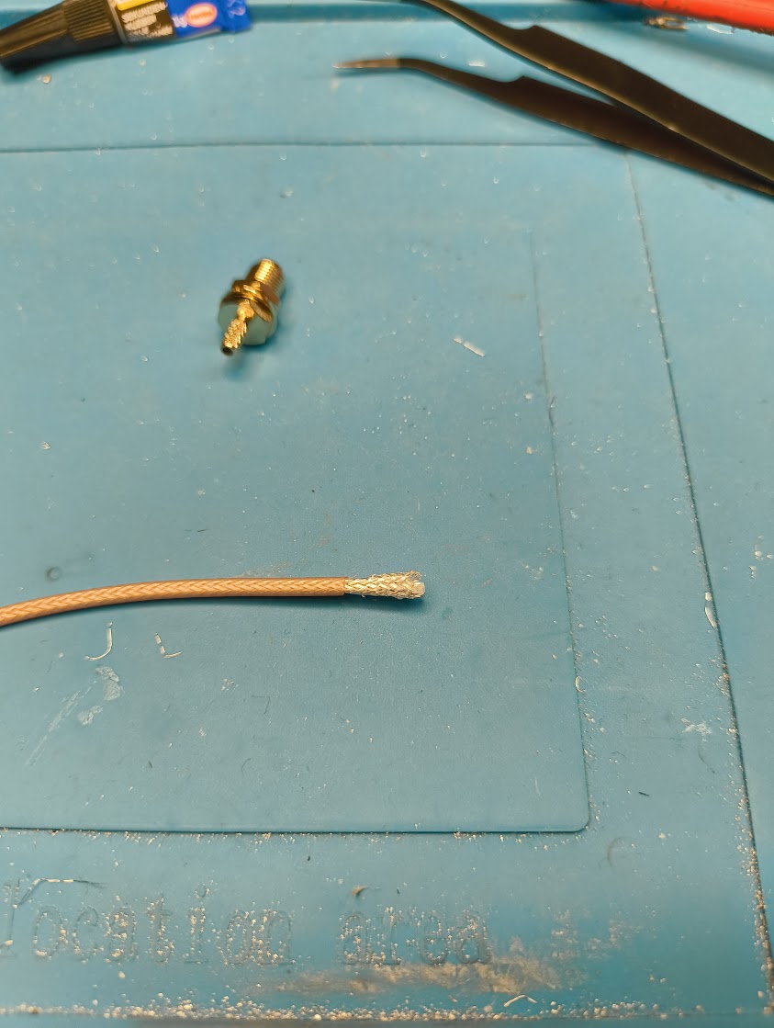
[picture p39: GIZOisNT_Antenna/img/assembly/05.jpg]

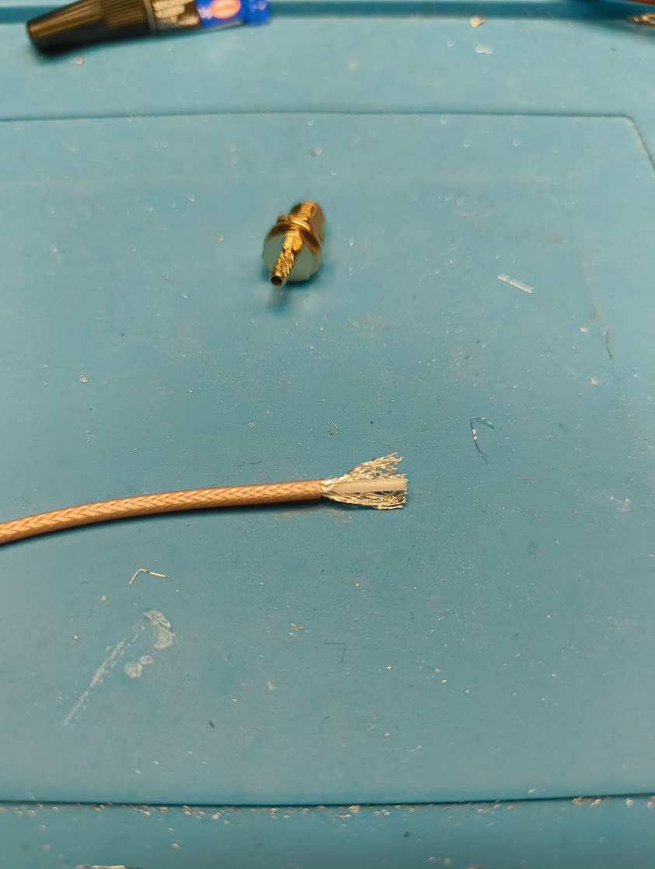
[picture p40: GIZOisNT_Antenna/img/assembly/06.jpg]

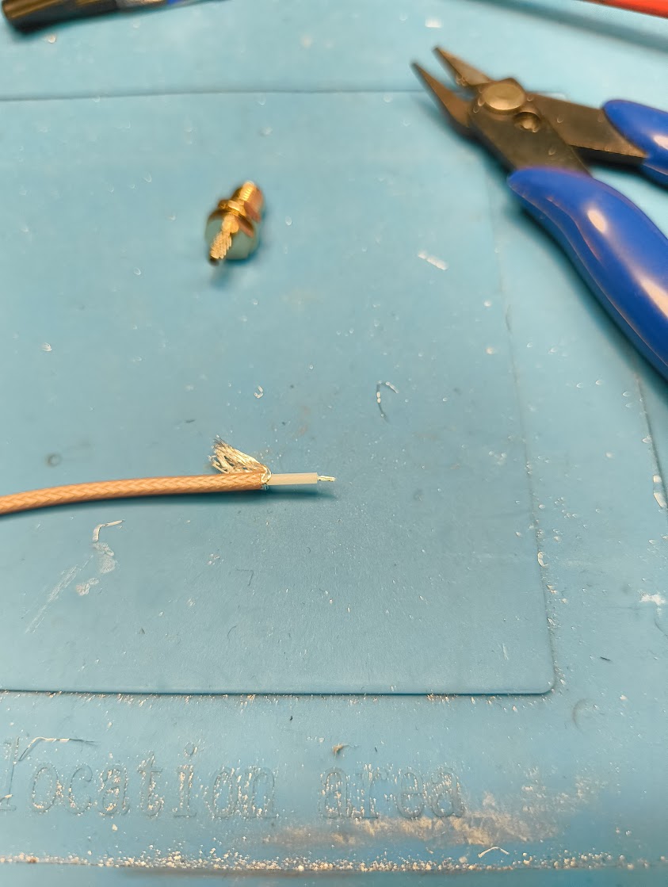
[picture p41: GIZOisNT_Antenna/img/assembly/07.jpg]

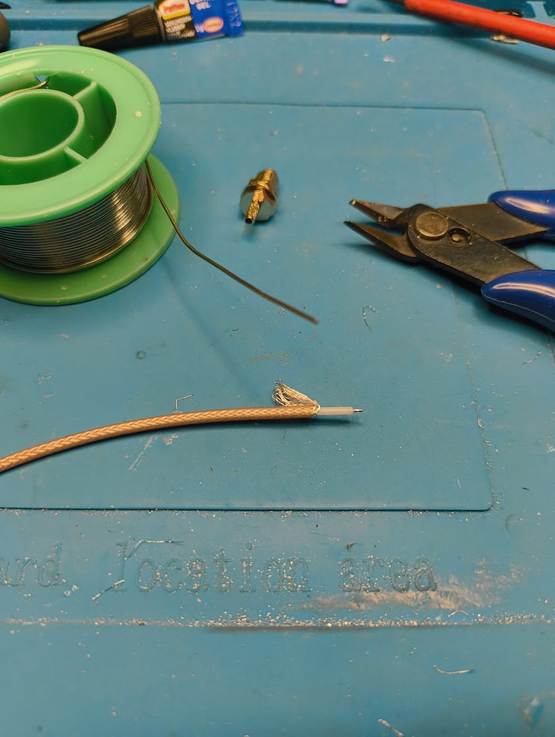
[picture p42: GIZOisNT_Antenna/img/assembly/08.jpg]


### 3. Install the RP-SMA connector

Clamp the pin of the RP-SMA connector in a soldering jig and apply a small amount of solder to the opening. Then solder the tinned center conductor of the coaxial cable to the pin. Ensure that NO solder protrudes beyond the edge of the SMA pin. Otherwise, you won't be able to insert it into the RP-SMA connector. Now, push the coaxial cable with the pin fully into the RP-SMA connector. Next, place the shielding over the end of the RP-SMA connector and slide the crimp sleeve over the shielding. Finally, use crimping pliers to crimp the sleeve onto the end of the RP-SMA connector.

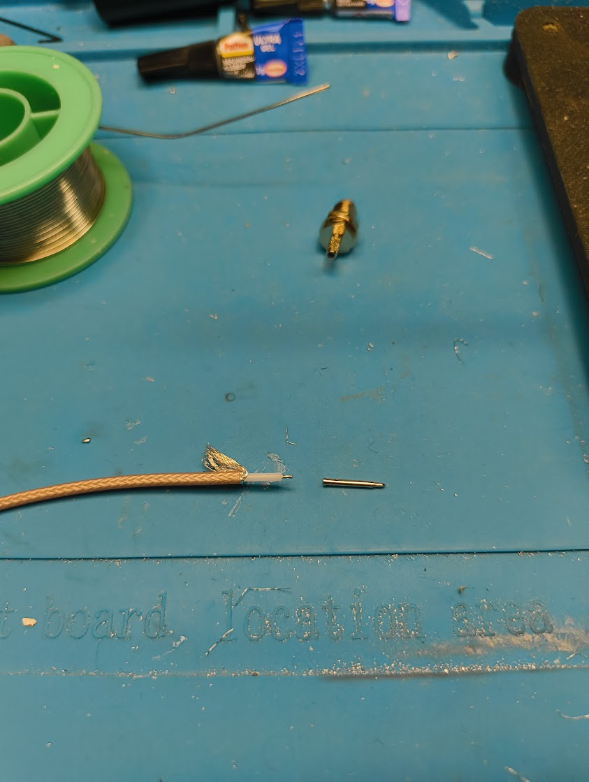
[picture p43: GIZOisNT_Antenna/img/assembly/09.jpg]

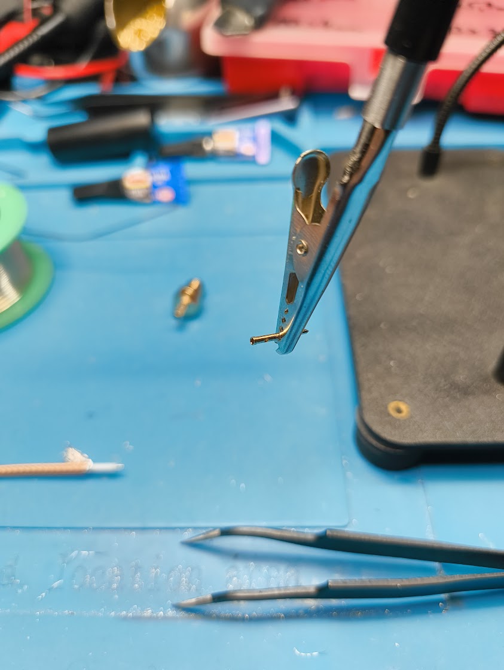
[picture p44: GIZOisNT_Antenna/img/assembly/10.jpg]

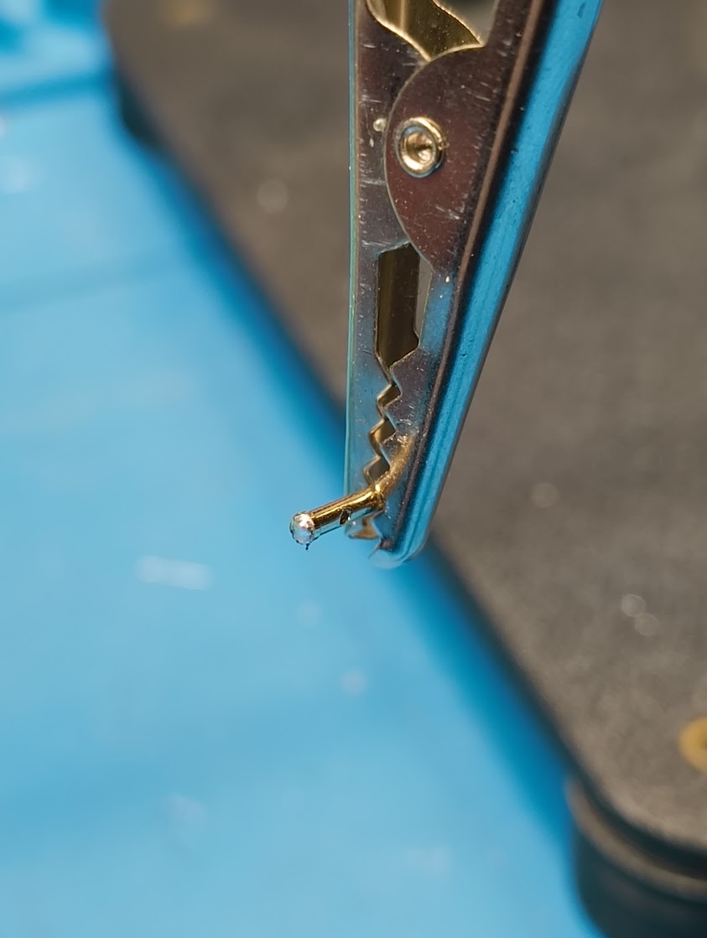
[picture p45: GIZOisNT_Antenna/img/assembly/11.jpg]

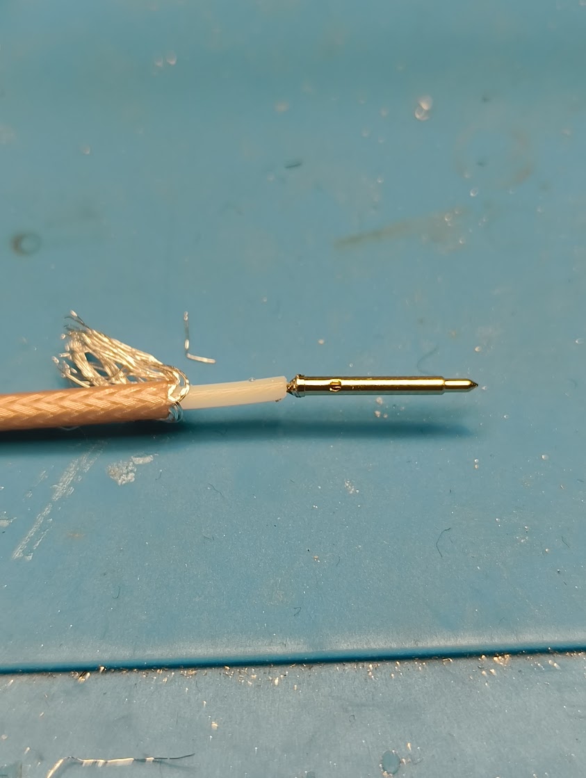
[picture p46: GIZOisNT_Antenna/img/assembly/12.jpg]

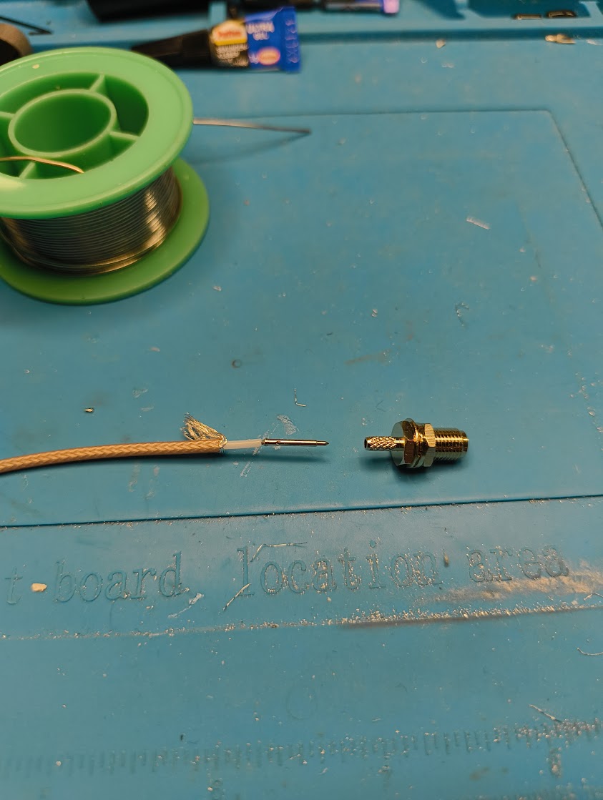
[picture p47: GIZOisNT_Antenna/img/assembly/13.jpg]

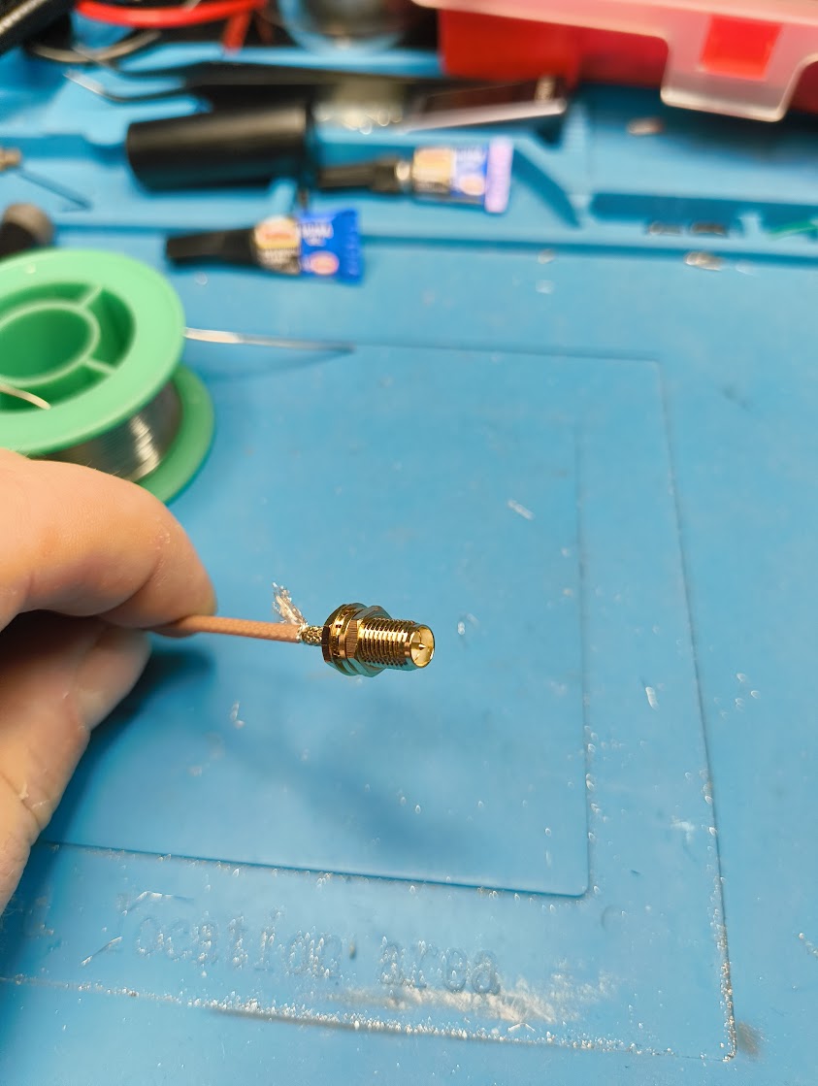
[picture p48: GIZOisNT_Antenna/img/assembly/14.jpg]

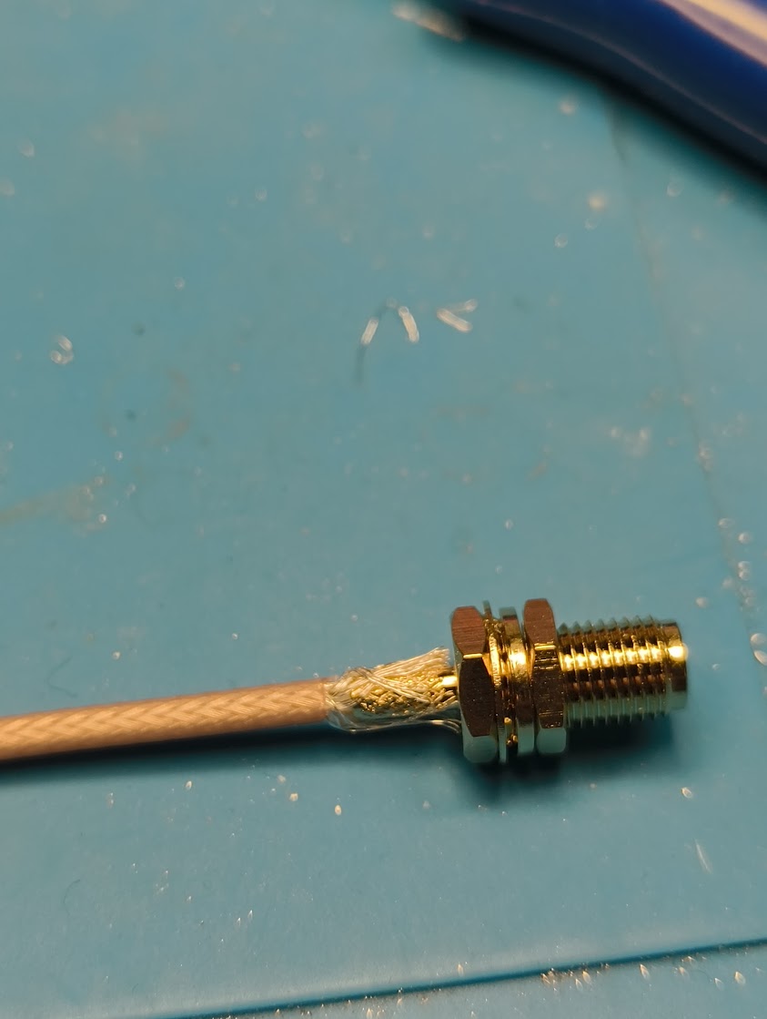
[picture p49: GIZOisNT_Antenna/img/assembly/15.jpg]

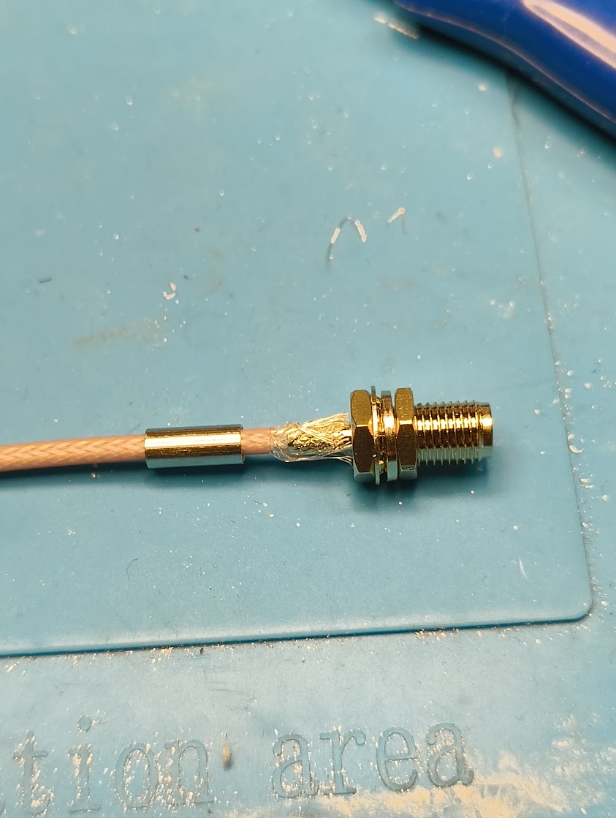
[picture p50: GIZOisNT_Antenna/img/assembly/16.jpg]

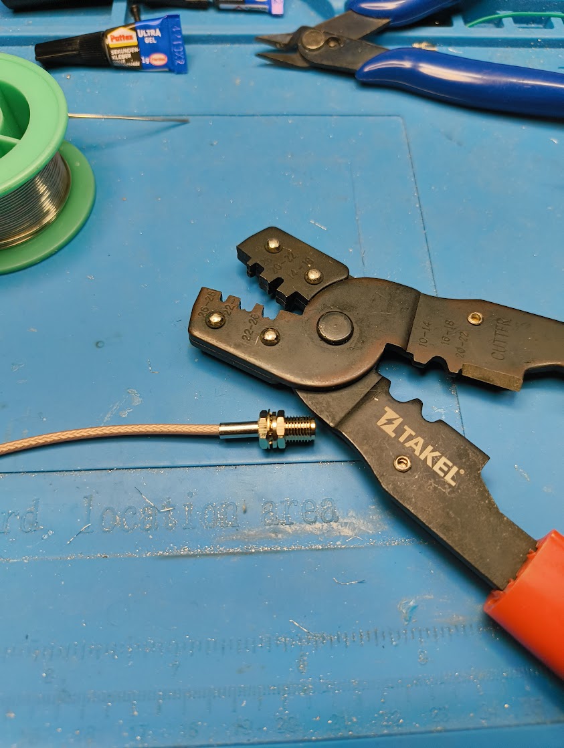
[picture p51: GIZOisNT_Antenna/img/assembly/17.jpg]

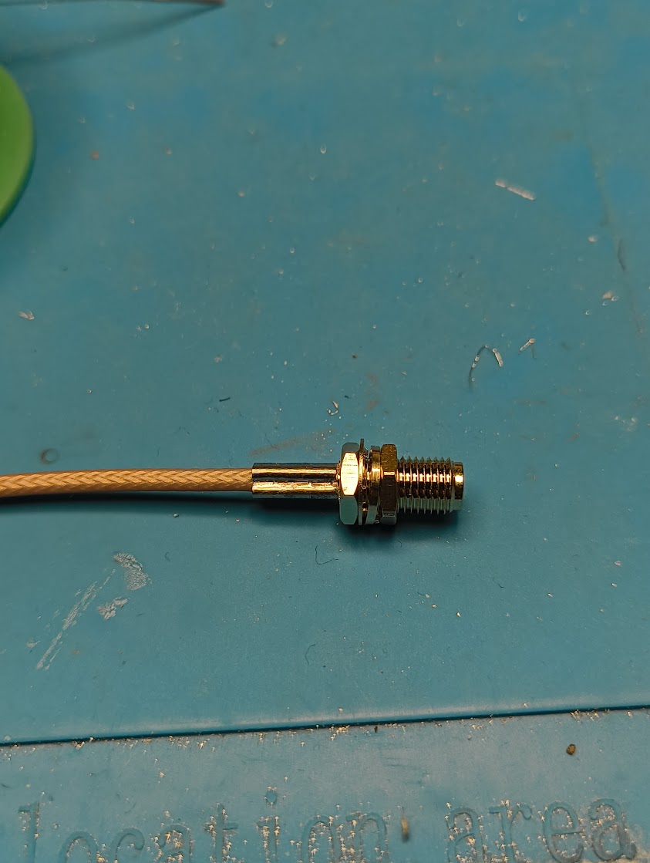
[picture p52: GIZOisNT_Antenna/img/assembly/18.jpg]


### 4. Ensure cable length

Now, insert the unstripped end of the cable with the RP-SMA connector into the threaded opening. When the RP-SMA connector is flush with the threaded end, 10mm should protrude from the TNC end. If it's too little, it will be difficult to attach the TNC connector. If it's too much, it will be very difficult to press the TNC connector into the TNC adapter. The coaxial cable is very stiff!

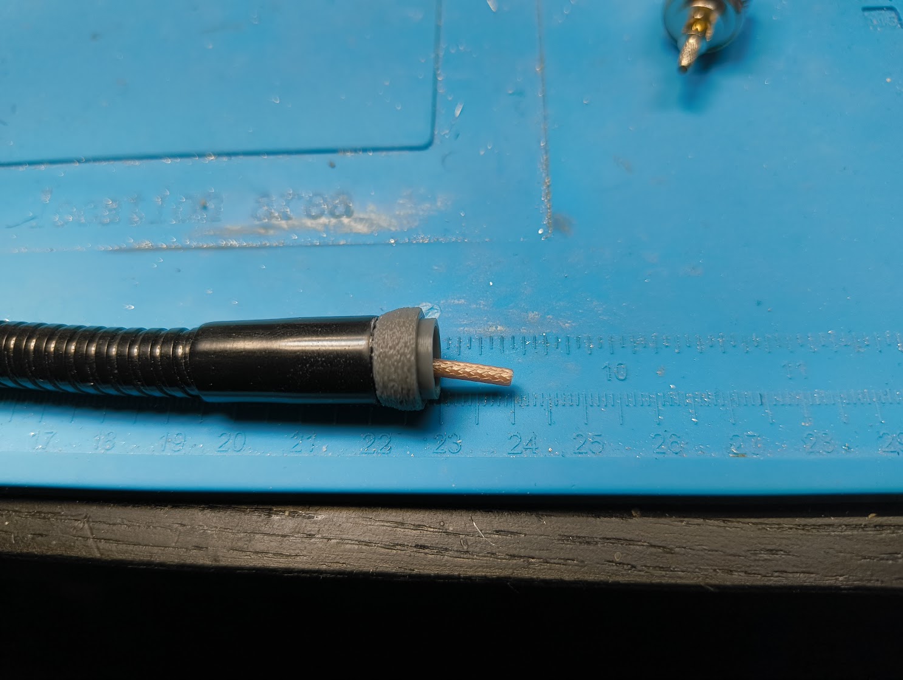
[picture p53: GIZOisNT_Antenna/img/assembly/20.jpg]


### 5. Install the TNC connector

Once you've ensured the correct length, pull the coaxial cable with the RP-SMA connector out of the gooseneck. Strip another 10-12 mm of insulation. Again, open the shielding (this time don't fold it back), strip 1-2 mm of insulation from the center conductor, and apply a small amount of solder. Now, push the coaxial cable back into the gooseneck and attach the crimp sleeve. Push it slightly into the TNC adapter, but still enough to remove it later. Now, apply a small amount of solder to the center conductor of the TNC connector. Be careful: DO NOT create a connection between the center conductor and the connector housing! Otherwise, you'll create a short circuit. Now, insert the center conductor of the coaxial cable far enough into the TNC connector so that you can solder them together. Now would be a good time to use a multimeter to test whether the TNC housing is making contact with the center conductor. If there's a short circuit, you'll need to reopen the solder joint and fix it. If not, you can proceed. Now, place the shielding on the end of the TNC connector, slide the crimp sleeve over it, and crimp it at the thin end.

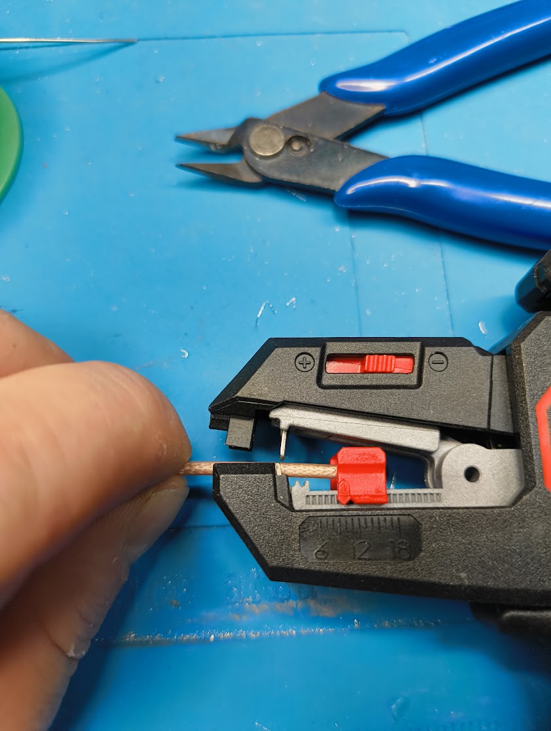
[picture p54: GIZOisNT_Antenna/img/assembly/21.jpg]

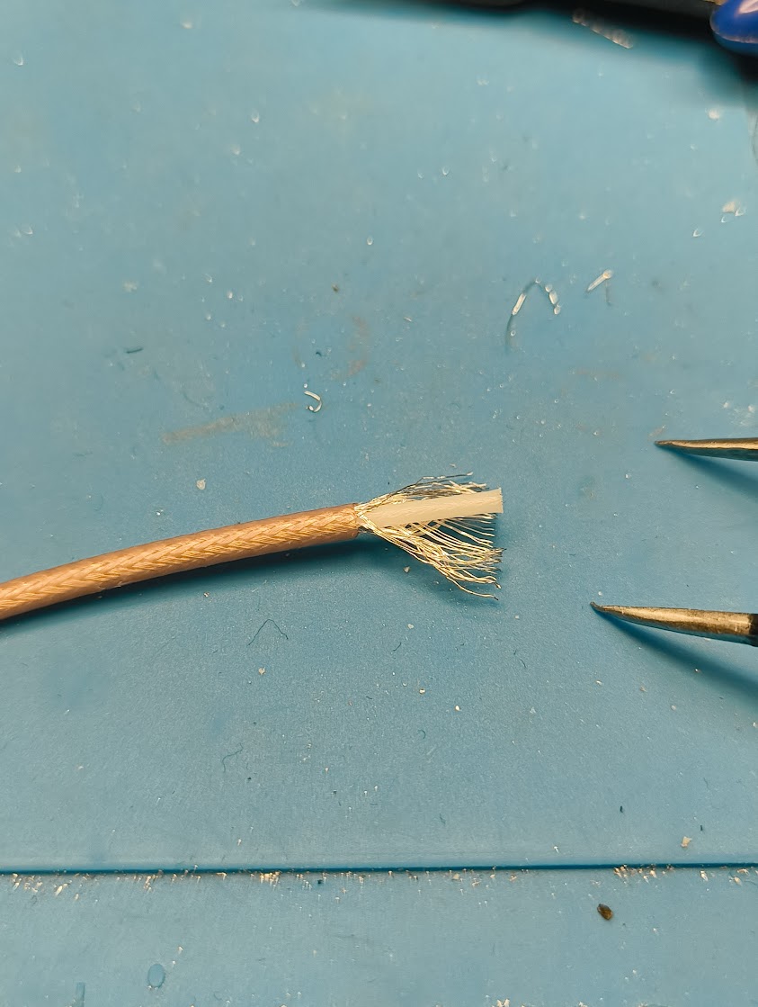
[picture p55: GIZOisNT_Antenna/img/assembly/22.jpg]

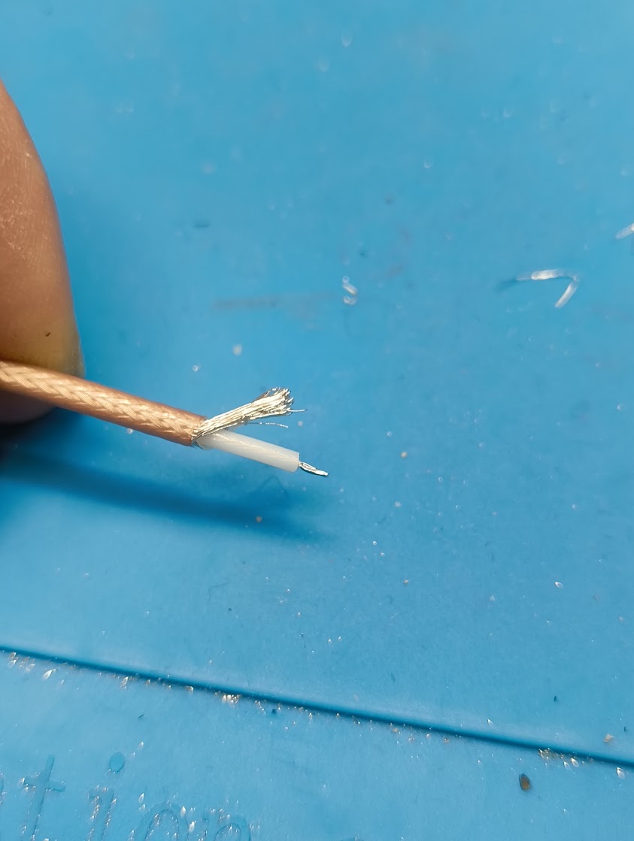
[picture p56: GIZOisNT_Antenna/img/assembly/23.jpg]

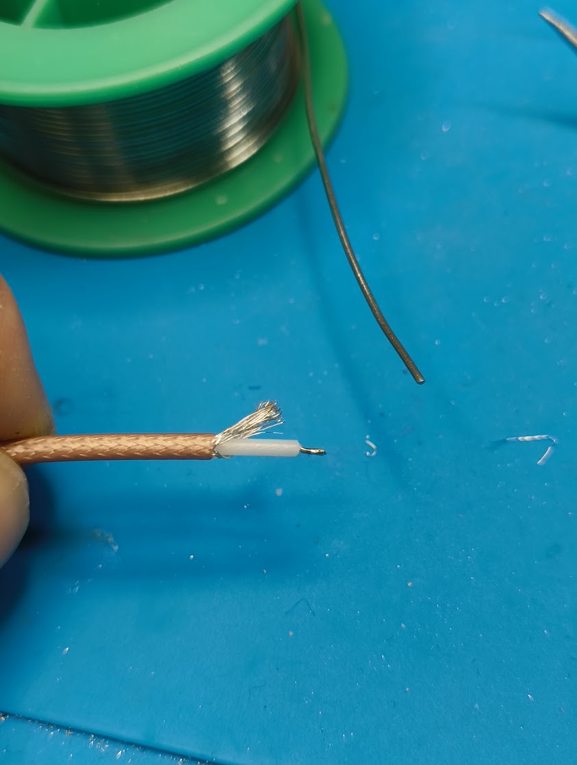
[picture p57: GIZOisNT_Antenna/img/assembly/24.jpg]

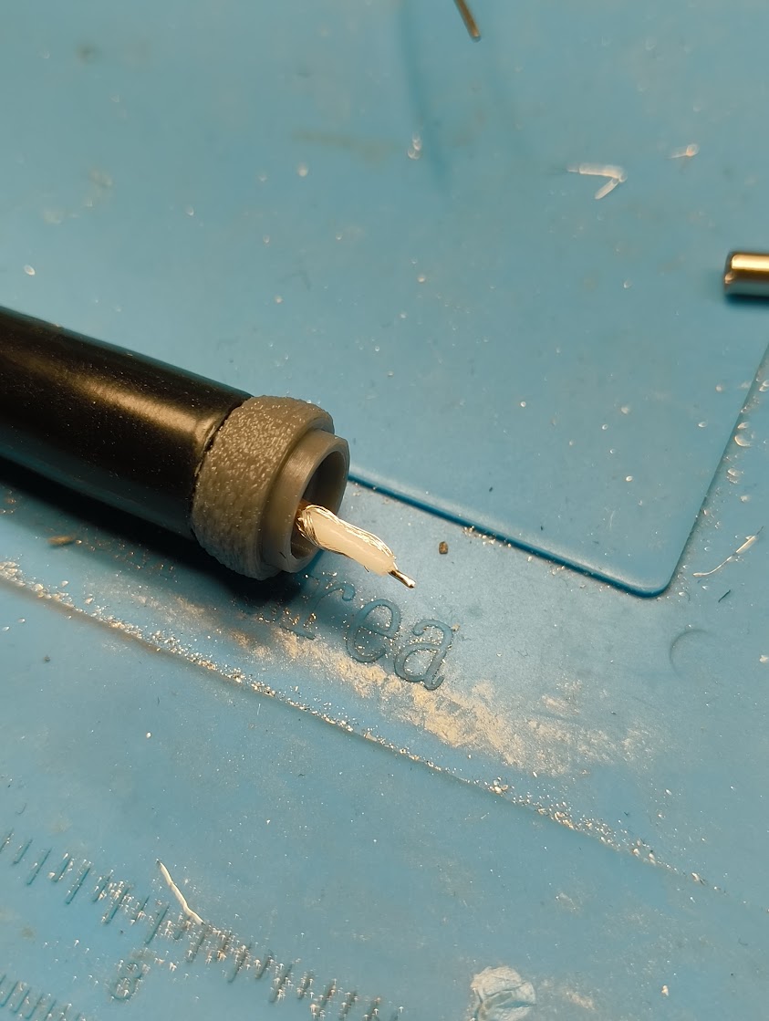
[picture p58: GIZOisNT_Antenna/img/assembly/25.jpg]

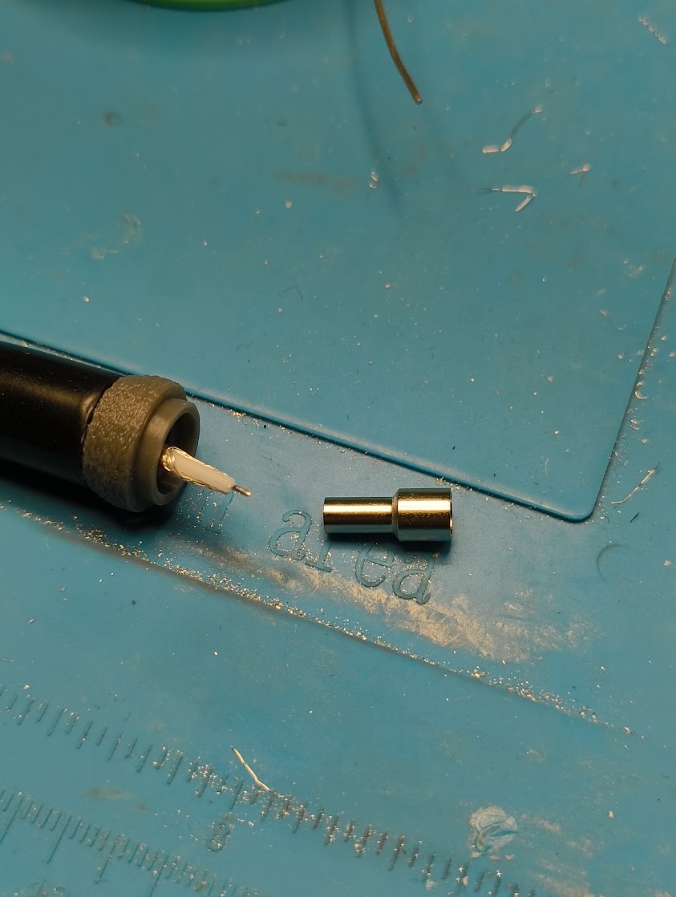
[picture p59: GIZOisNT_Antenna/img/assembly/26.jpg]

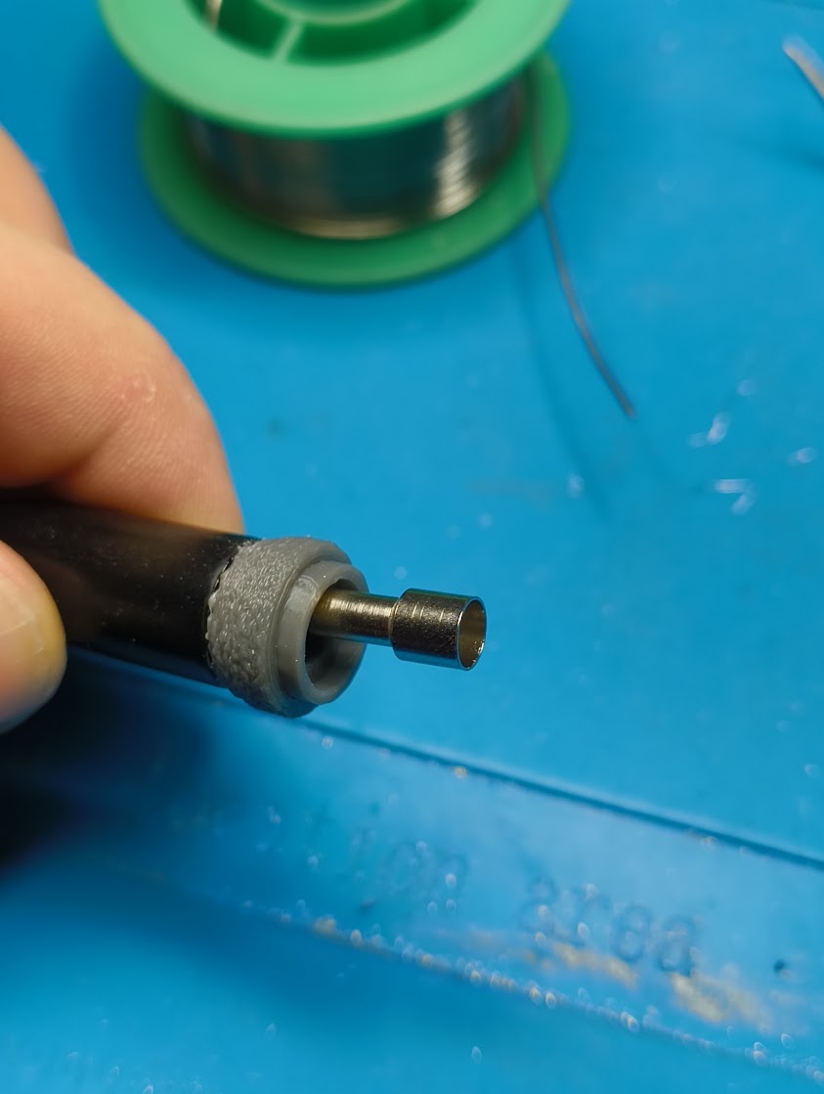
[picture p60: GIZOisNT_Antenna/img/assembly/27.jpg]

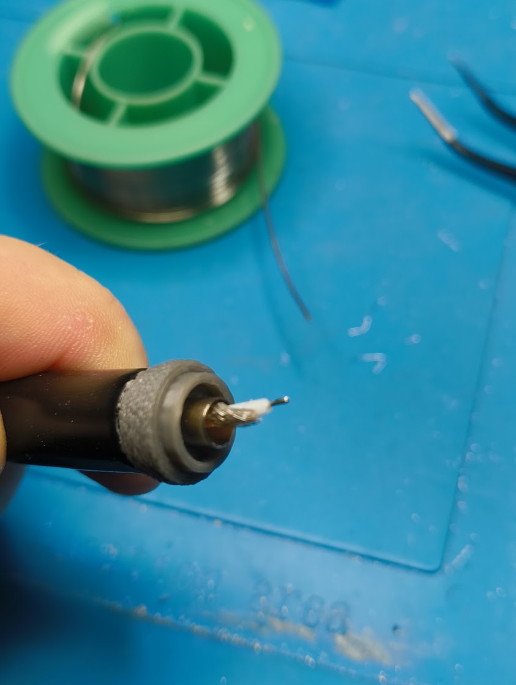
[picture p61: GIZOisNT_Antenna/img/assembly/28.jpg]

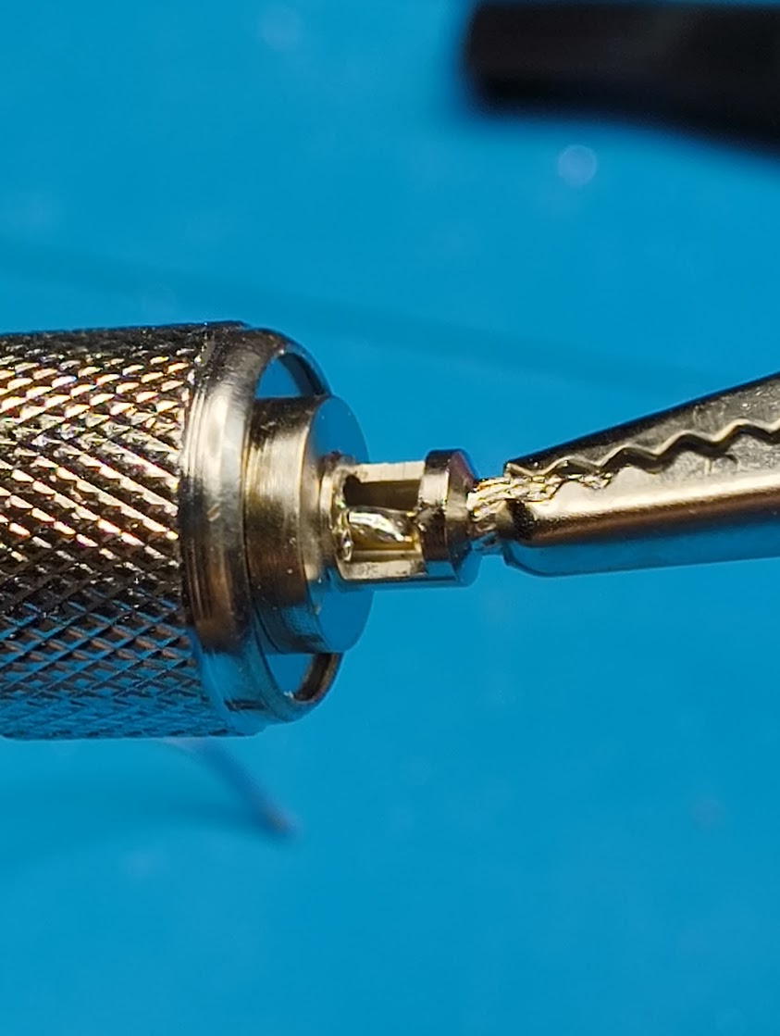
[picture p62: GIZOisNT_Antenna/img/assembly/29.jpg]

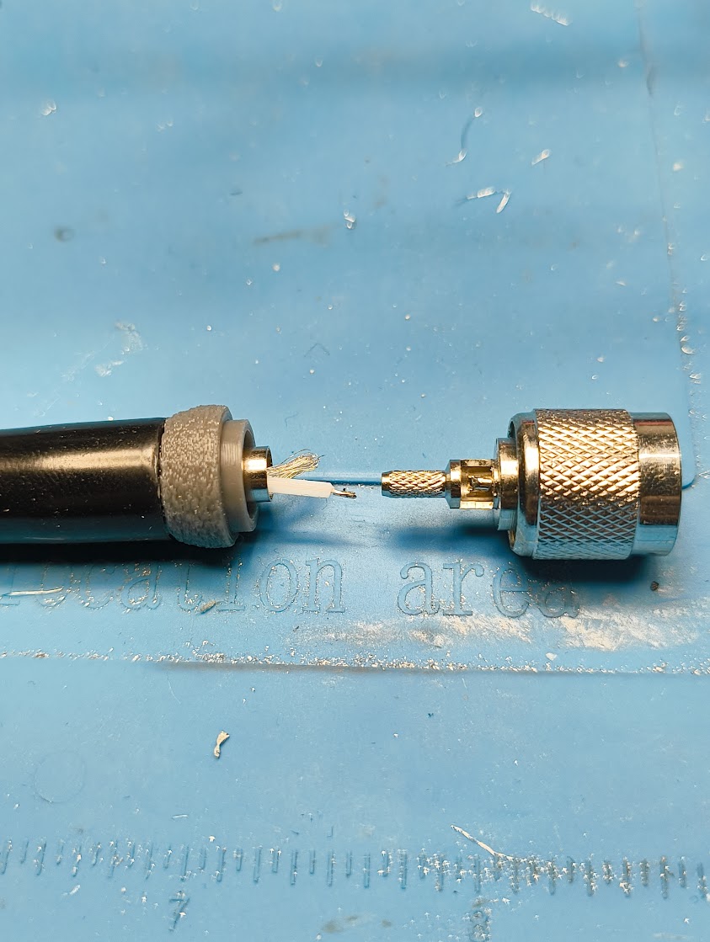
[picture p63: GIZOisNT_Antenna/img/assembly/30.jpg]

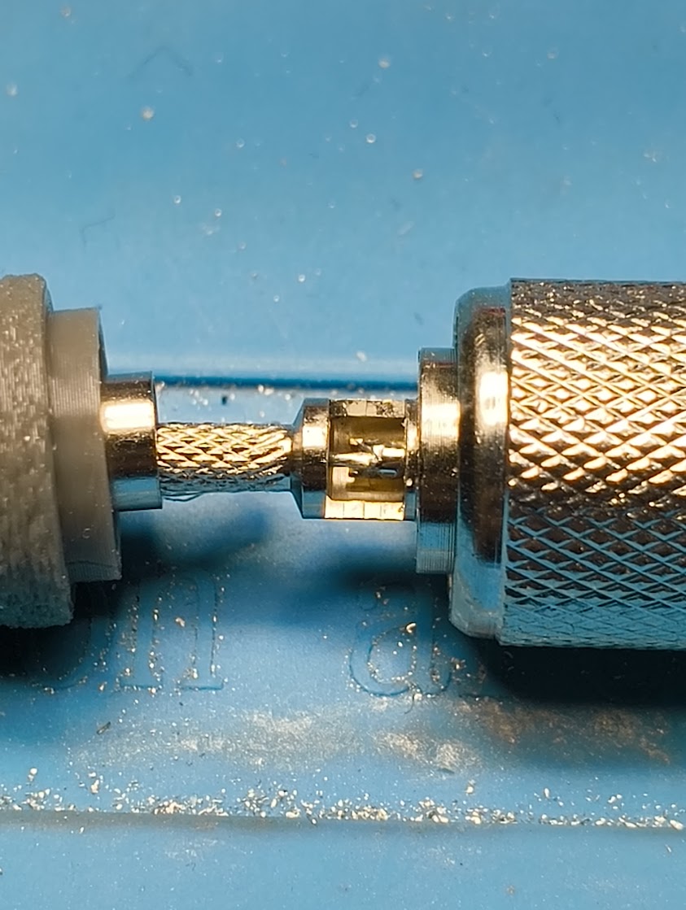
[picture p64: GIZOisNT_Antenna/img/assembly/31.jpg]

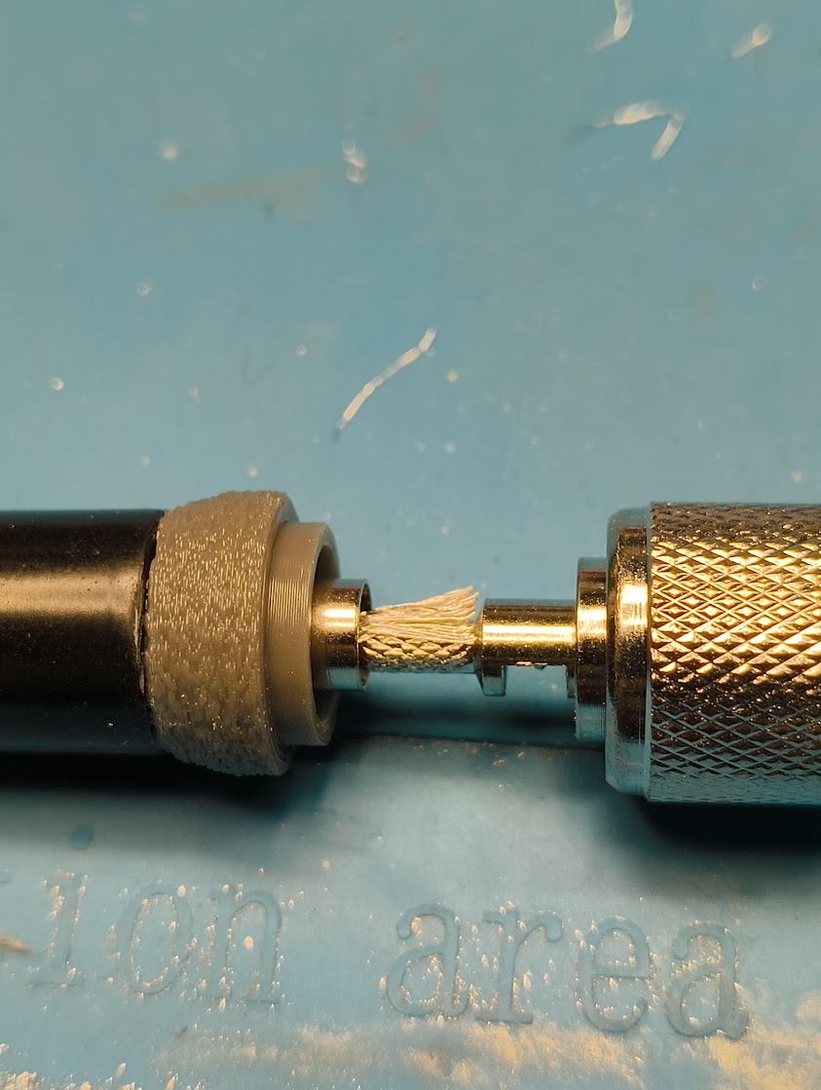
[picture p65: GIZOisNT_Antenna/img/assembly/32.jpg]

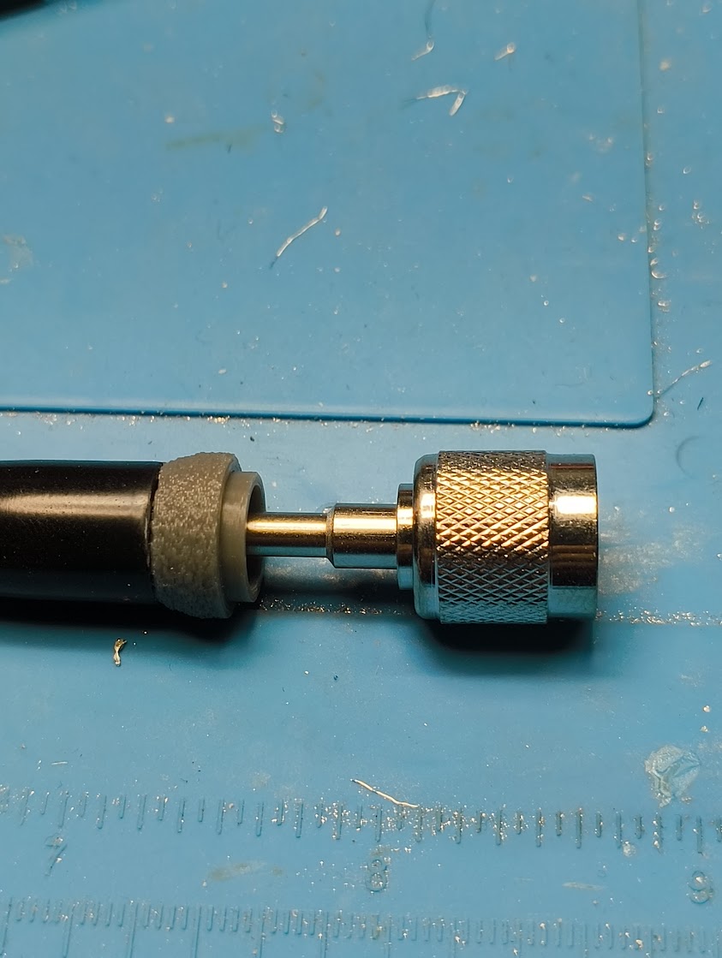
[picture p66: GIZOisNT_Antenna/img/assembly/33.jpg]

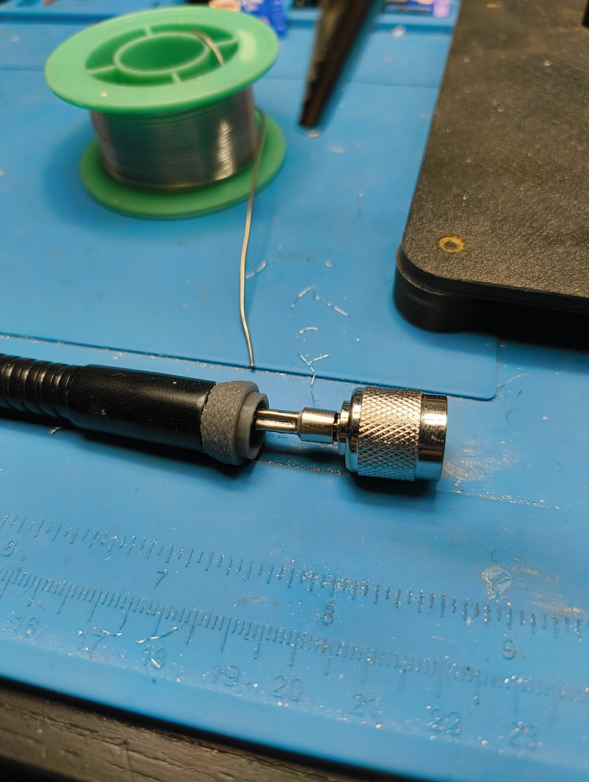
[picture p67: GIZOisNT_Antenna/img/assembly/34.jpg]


### 6. Glue in the TNC connector

Apply glue to the inside of the TNC adapter and the thick part of the crimp sleeve. Then press the TNC connector firmly into the TNC adapter.

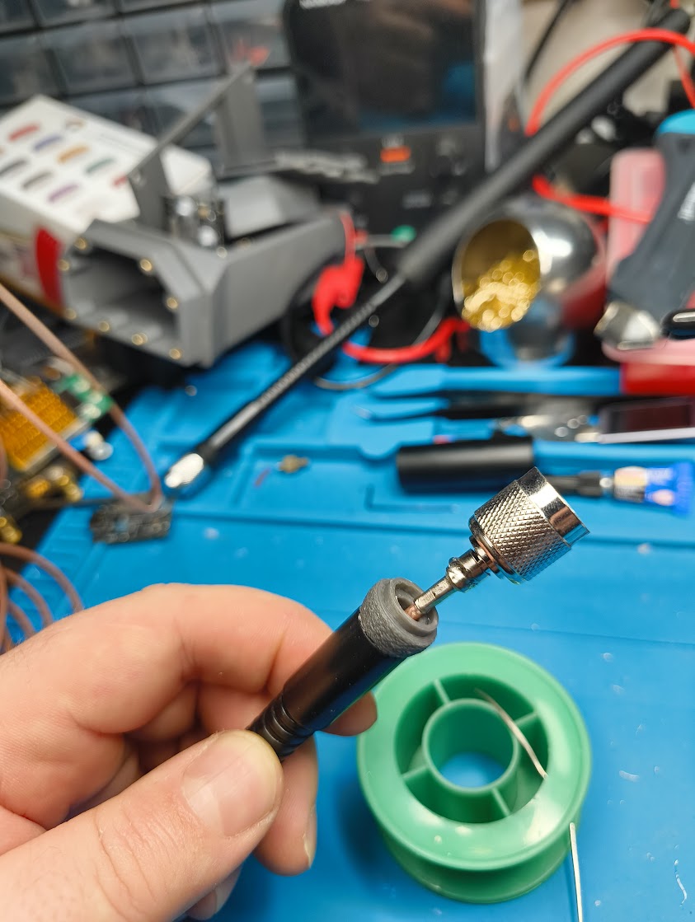
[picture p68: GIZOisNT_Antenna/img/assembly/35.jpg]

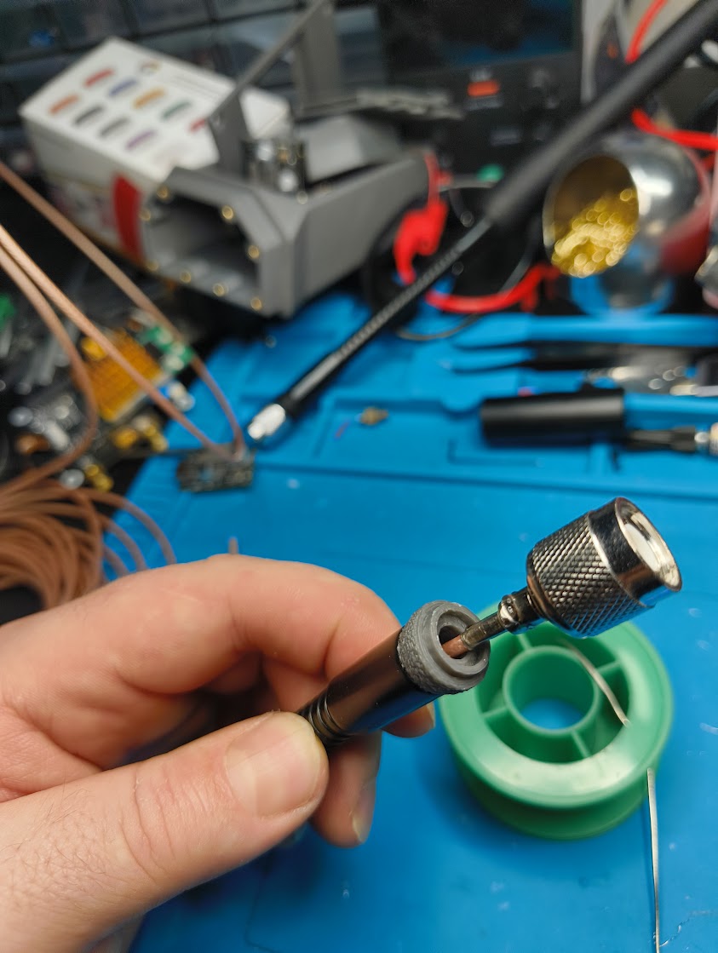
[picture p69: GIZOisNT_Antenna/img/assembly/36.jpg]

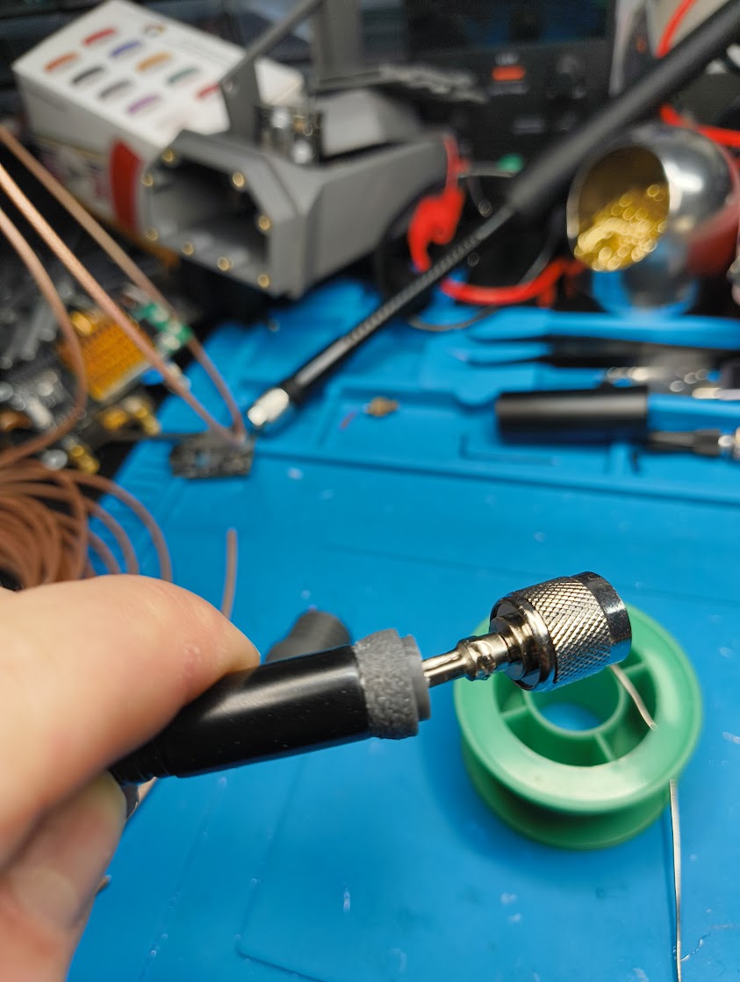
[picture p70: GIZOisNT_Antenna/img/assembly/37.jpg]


### 7. Mount and glue in the RP-SMA connector

Now slide the RP-SMA adapter over the RP-SMA connector so that the connector protrudes slightly from the adapter. Apply glue to the external thread of the gooseneck and press the RP-SMA adapter firmly onto the external thread of the gooseneck. Then screw the RP-SMA connector in place.

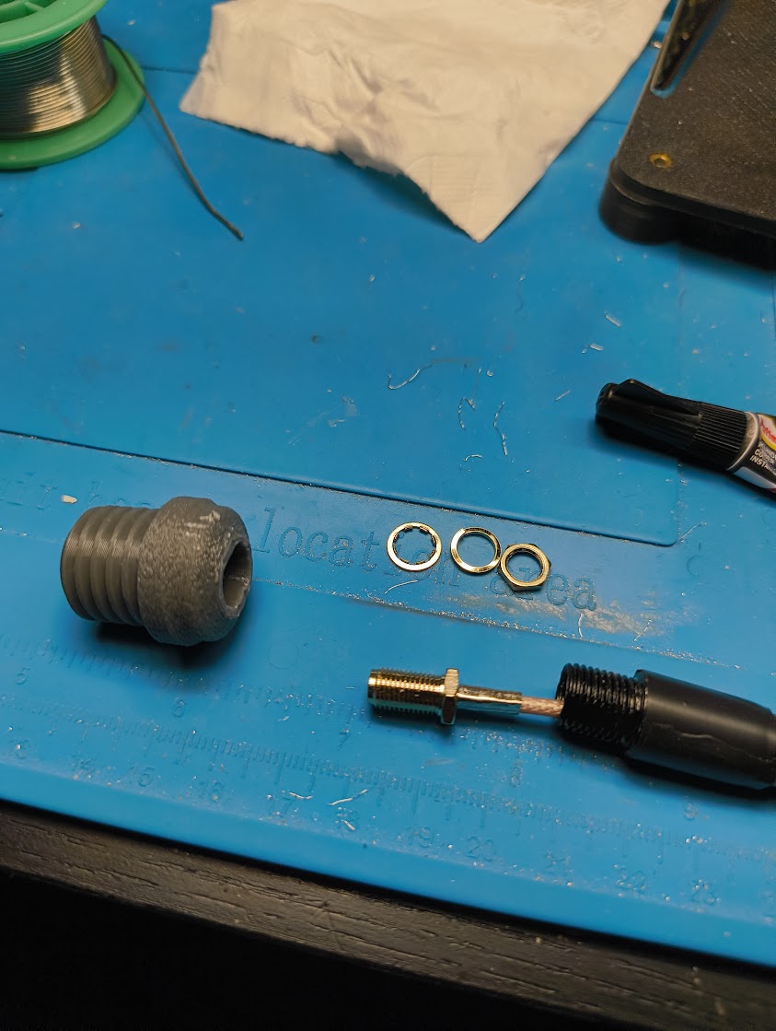
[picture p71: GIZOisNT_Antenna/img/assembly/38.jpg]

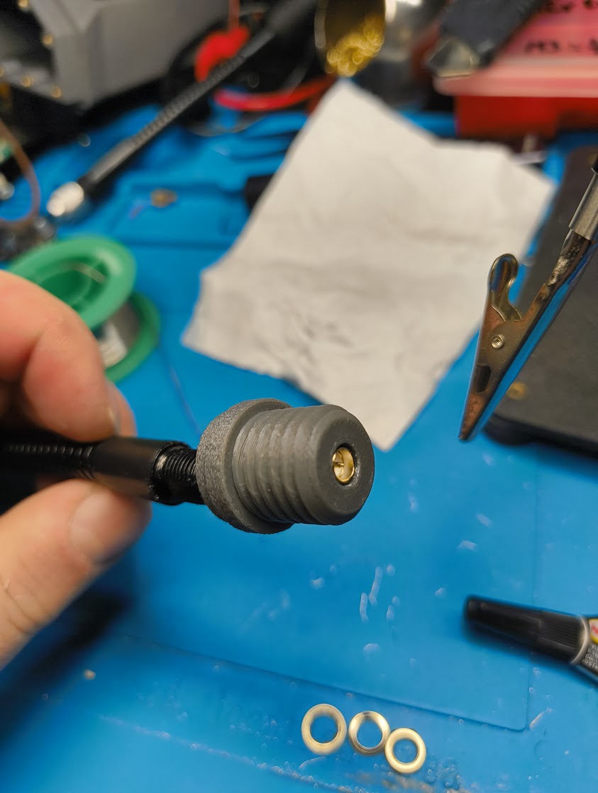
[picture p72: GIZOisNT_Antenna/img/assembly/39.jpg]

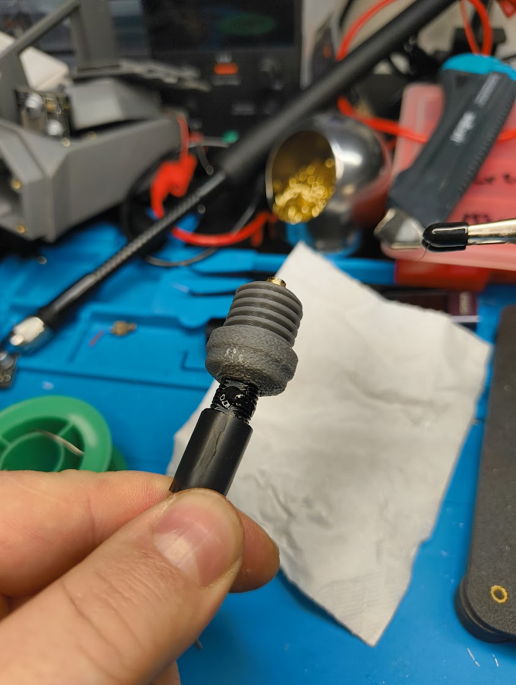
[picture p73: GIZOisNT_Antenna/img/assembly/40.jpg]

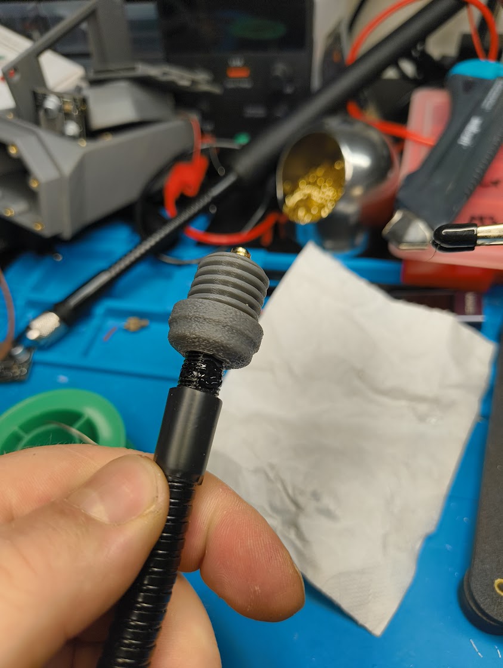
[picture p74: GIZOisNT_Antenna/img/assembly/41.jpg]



### 8. Final assembly

Now you can screw your antenna onto the RP-SMA connector. Once that's done, glue the cap to the tube, and then screw the tube onto the RP-SMA adapter.

final_01
final_02

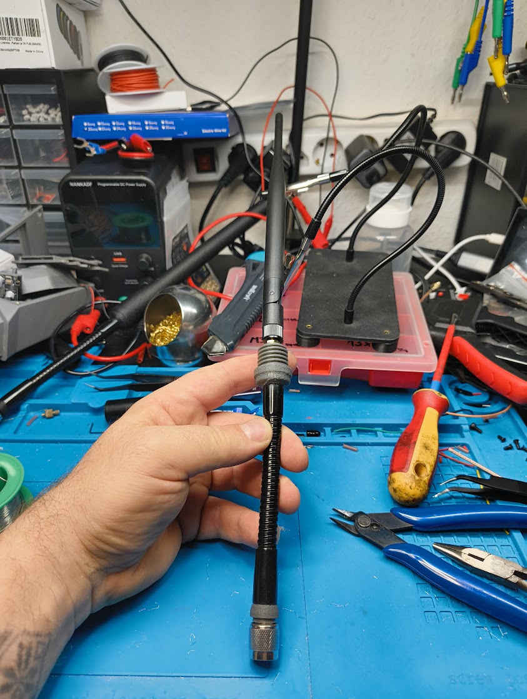
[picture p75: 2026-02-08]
GIZOisNT_Antenna/img/assembly/43.jpg

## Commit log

2025-11-13 Add new enclosures
    [RPI 4 openMANET Radio Case with Waveshare 3s ups (back panel).stl, RPI 4 openMANET Radio Case with Waveshare 3s ups (gasket).stl, open manet enclosure WAVESHAR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]
2025-11-13 Add antennas
2025-11-13 Update case
    [open manet enclosure WAVESHARE UPS D hatch REV1.stl.stl, open manet enclosure WAVESHARE UPS D hatch.stl, open manet enclosure pisugar ups hatch REV1.stl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]
2025-11-20 Initial commit.
    [openMANET_enclosure_rpi4_ups_battery_rj45.stl, openMANET_mounting_plate.stl, openMANET_top_usbc_rj45_ntype_sma.stl]
2025-11-20 Screws instructions
2025-11-21 Updated stl
    [openMANET_enclosure_rpi4_ups_battery_rj45.stl, openMANET_mounting_plate.stl, openMANET_top_usbc_rj45_ntype_sma.stl]
2025-11-21 Screws for enclosure
    [openMANET_enclosure_rpi4_ups_battery_rj45.stl, openMANET_top_usbc_rj45_ntype_sma.stl]
2025-12-03 Move antenna to fit UPS
    [open manet enclosure WAVESHARE UPS D hatch REV1.stl.stl, open manet enclosure WAVESHARE UPS D main body.stl]
2025-12-14 Slimmed down version with rounded corners.
    [OpenChubnet_slim.3mf, openMANET_enclosure_rpi4_ups_battery_rj45.stl, openMANET_stencil_sma_large.stl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]
2025-12-19 Add Hammond case
2026-01-06 Remove STL for OpenNot5
    [RPI 4 openMANET Radio Case with Waveshare 3s ups (back panel).stl, RPI 4 openMANET Radio Case with Waveshare 3s ups (gasket).stl]
2026-02-08 Add assembly images for GIZOisNT Antenna
    Add 43 assembly JPEGs (01.jpg–43.jpg) to GIZOisNT_Antenna/img/assembly. These images provide step-by-step assembly documentation for the GIZOisNT antenna and will be used in the project's assembly gu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
2026-02-08 Add antenna assembly guide and images
    Add a new assembly.md documenting step-by-step instructions to build the antenna (components list, stripping, soldering, crimping, glueing and final assembly) with accompanying photos. The guide incl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
2026-02-08 Add GIZOisNT antenna images
    Promo Pictures
2026-02-08 Add antenna parts images
    Add 16 image assets to GIZOisNT_Antenna/img/parts: SMA adapters (adapter_sma_01..04), TNC adapters (adapter_tnc_01..04), caps (cap_01..04), and 200mm tubes (tube_200mm_01..04). These provide visual r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
2026-02-08 Add 3D model STL files for antenna parts
    Add binary STL assets for the GIZOisNT_Antenna project: adapter_sma.stl, adapter_tnc.stl, cap.stl, and tube_100mm.stl, tube_150mm.stl, tube_200mm.stl under GIZOisNT_Antenna/model files. These files p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
    [adapter_sma.stl, adapter_tnc.stl, cap.stl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]
2026-02-08 Anycubic print files
    Print project file and gcode for Anycubic Kobra S1
    [GIZOisNT.3mf]
2026-02-08 Add SketchUp model for GIZOisNT antenna
    Add initial SketchUp (.skp) model GIZOisNT_v1.skp under GIZOisNT_Antenna/Sketchup. This commit introduces the binary 3D model for the GIZOisNT antenna design so the project can include and version th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
    [GIZOisNT_v1.skp]
2026-02-08 Add GIZOisNT antenna docs and print files
    Add initial documentation and print-resource files for the GIZOisNT tactical gooseneck antenna. Includes a README with project overview, parts list, assembly link and usage notes; a model files index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
2026-02-08 Add GIZOisNT print entry and image
    Add an "Other Prints" section to README with a table entry linking GIZOisNT (GIZOisNT_Antenna/README.md) and insert the GIZOisNT photo into the Photo Gallery (GIZOisNT_Antenna/img/Final_02.jpg).
2026-02-14 Add Hammond STLS
    [OpenMANET halow enclosure carrier tray rev3.stl, OpenMANET halow enclosure top cap rev3.stl]
